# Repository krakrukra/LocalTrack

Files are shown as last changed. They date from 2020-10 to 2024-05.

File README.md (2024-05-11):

# LocalTrack  
  
#### Русская версия документации доступна [здесь](https://github.com/krakrukra/LocalTrack/blob/master/extra/wiki/rus/README.md)  
  
This device is an open source (both firmware and board level design) GPS data logger.  
You mount it with built-in magnets on some vehicle, flip the power switch and the location  
data is saved into internal flash storage. After some tracks were recorded, you can  
retrieve the device again and extract GPX track files via USB. You can then pass these  
files into mapping/analysis software of your choice, for example [viking](https://sourceforge.net/projects/viking), to get an  
easy to work with representation of recorded location data.  
  
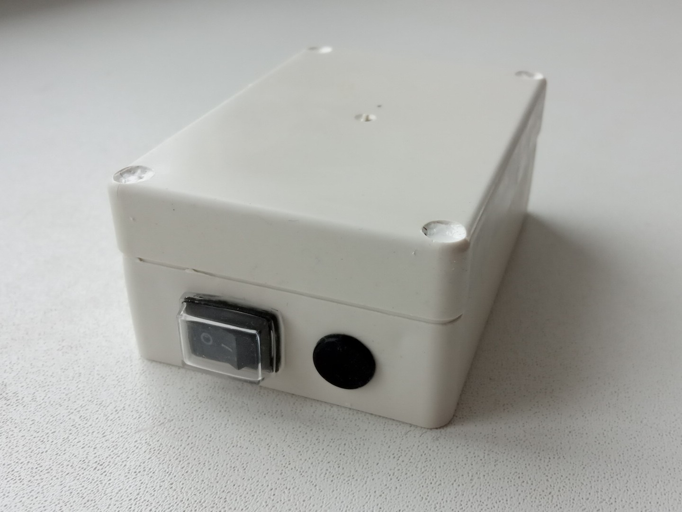
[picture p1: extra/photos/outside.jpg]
outside
  
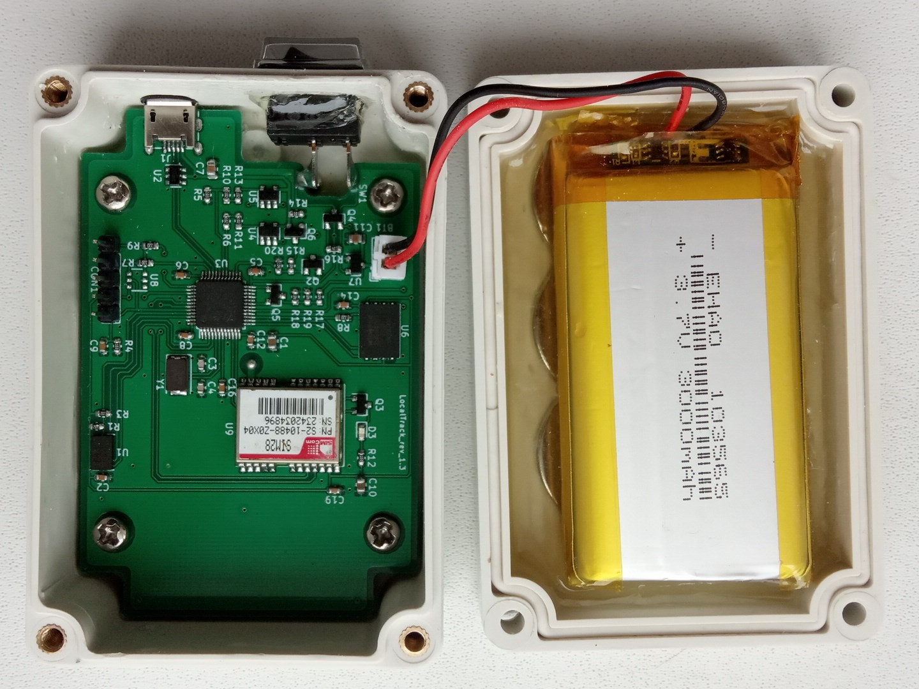
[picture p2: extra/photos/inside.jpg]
inside
  
  
This device is intended for use in applications where real-time tracking is not required,  
but other advantages of network-disconnected design are desirable, such as:  
  
1. No need to pay your cellular service provider.  
  
2. Local file storage, so you don't have to trust your data to some proprietary  
manufacturer's software or depend on a particular service being provided.  
  
3. Logger is harder to detect; if discovered, it is hard to trace where it came from,  
as it does not have information like IMEI, IMSI, payment history, etc. linked to it.  
  
4. Less power consumption and longer battery life.  
  
**CHECK THE [WIKI](https://github.com/krakrukra/LocalTrack/wiki) FOR HOW-TO-USE INFORMATION**  
  
---
  
## hardware
  
Project is designed using KiCad 6.0.11  
Check KiCad pcb file for PCB manufacturing info  
Check KiCad sch file + BOM.txt for component info  
  
Uses integrated full-speed (12Mbit/s) USB2.0 peripheral, with  
96MiB of available on-board flash memory for data storage;  
measured speeds for MSD access: read 800-850 KiB/s, write 700-750 KiB/s  
  
Fully assembled unit has dimensions of 85x55x32mm and weight of 175 grams.  
Hardware programmer device used in this project is [ST-Link V2](https://www.aliexpress.com/item/1823628996.html)  
  
SIM28 may come in several variants which have different USART speeds by default.  
Firmare here expects 9600 baudrate version. If you have different module version  
you will need to modify USART1 configuration in main.c and peripherals.c files.  
  
Device has a 3000mAh li-po battery and can function with battery voltage above 3V.  
If lower voltage is detected, device enters low battery mode and waits until  
the battery is recharged. Current consumption while tracking is around 40mA;  
while waiting in sleepmode (eg. due to lack of movement) it is less than 1mA.  
This results in about 70 hours of active tracking before battery is depleted.  
Battery can be charged via USB with up to 1A of current, so make sure to pick  
capable charging adapter and USB cable. Also, keep in mind that you will need  
a cable with extra long 8mm micro USB plug, instead of the usual 5.4mm plug.  
  
## firmware  
  
Programming language used = C  
Flashing software used = openocd 0.12.0  
IDE used = emacs text editor + Makefile  
  
The firmware was developed on debian 11.3 system, using gcc-arm-none-eabi  
toolchain (compiler, linker, binutils) and it does use gcc specific extentions.  
it was successfully compiled and tested with arm-none-eabi-gcc version 12.2.1  
  
Depends on libgcc.a, which is included in this repository. Linker script,  
startup code and openocd configuration files are included here as well.  
  
For easy in-field updates, you can use the DFU bootloader. There is a dfu  
firmware image available in **/firmware/firmware\_RRNNN.dfu** file. The name  
format is this: RR stands for board revision (13 = rev 1.3) , NNN stands  
for firmware version. For example, firmware\_13001.dfu means board  
revision 1.3, firmware version 1  

To automate firmware build process you can use make utility. If you  
open terminal in **/firmware/** directory, you could run these commands:  
  
> make  
> make upload  
> make dfu  
> make clean  
  
"make" will compile source code and create several files, among them  
is firmware.bin which contains firmware to flash. "make upload" will  
flash this file via St-Link V2 programmer. Make sure to connect the  
programmer to the board properly, before you plug it into PC and run the  
command. "make dfu" will create a DFU firmware image from firmware.bin  
which can be used later by DFU flashing software. "make clean" will  
delete all the compiled or temporary files created by previous commands.  
  
## directories info  
  
#### /firmware/ ------------- contains makefile, linker script, source files; this is a build directory  
/firmware/cmsis/ ------- header files from CMSIS compliant [STM32F0xx standard peripherals library](https://www.st.com/content/st_com/en/products/embedded-software/mcus-embedded-software/stm32-embedded-software/stm32-standard-peripheral-libraries/stsw-stm32048.html)  
/firmware/stdlib/ ---------- standard statically linked libraries (libgcc.a)  
/firmware/openocd/ ------- standard configuration files for openocd 0.12.0  
/firmware/fatfs/ ---------- [chan fatfs](http://www.elm-chan.org/fsw/ff/00index_e.html) filesystem module + W25N01GVZEIG disk driver  
/firmware/usb/ ------------ USB system and MSD class device implementation  
/firmware/main/ ------- main application files, interrupt vector table, IRQ handlers and startup code  
/firmware/dfuse-pack.py ------- python script to create .dfu firmware images  
/firmware/linkScript.ld ------- custom linker script for the GNU linker (ld)  
/firmware/Makefile ------- file used by GNU make utility for build automation  
/firmware/firmware_13NNN.dfu ------ pre-compiled firmware image in DfuSe format (STM32)  
  
#### /hardware/ ------------------- contains KiCad project, schematic, PCB files  
/hardware/LocalTrack.symbols/ ---- project specific symbol library  
/hardware/LocalTrack.pretty/ ----- project specific footprint library  
/hardware/gerbers/ ----------- gerber+excellon fabrication output files  
/hardware/BOM.txt --------- list of parts and accessories needed for DIY assembly  
  
#### /mechanical/ ------------------- contains device's mechanical information  
/mechanical/drawings/ ---- mechanical drawings for some of the parts  
/mechanical/KH-F20.FCStd --- freecad model for the plastic enclosure  
  
#### /extra/ -------------------  contains pictures, documentation, etc.  
/extra/photos/ ---------------- photos of the device  
/extra/wiki/ ------------------ github wiki pages  
  
## contact info  
  
if you have a problem / question / feature request, here are your options for contacting me:  
send me an email to krakrukra@tutanota.com  
create a new github issue (check [closed issues](https://github.com/krakrukra/LocalTrack/issues?q=is%3Aissue+is%3Aclosed) first)  
also, you can check out my [youtube channel](https://www.youtube.com/channel/UC8HZCV1vNmZvp7ci1vNmj7g)  
  
For extra security, you could use my PGP public key saved in [/extra/pubkey.asc](https://github.com/krakrukra/LocalTrack/blob/master/extra/pubkey.asc).

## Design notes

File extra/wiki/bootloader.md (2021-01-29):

LocalTrack provides end user an ablity to update firmware  
over USB using DFU bootloader. To do so, you will need to  
install some dedicated software on your PC and connect the  
LocalTrack to this same PC, while your device is in DFU mode.  
Then, you feed a particular firmware image in DfuSe format  
to this dedicated software and wait for it to finish the update.  
The latest firmware image is available in the repository, in  
**/firmware/firmware_13nnn.dfu** file, where nnn is a number  
which stands for firmware version (eg. firmware_13000.dfu);  
  
There are 2 ways to enter DFU mode. If your device is already  
functional, you can get into DFU mode by adding "ENTER_DFU_MODE"  
configuration command to config.txt file. Once you disconnect  
LocalTrack from PC and then connect it again, device will delete  
config.txt and enter DFU mode instead of usual disk mode. To  
exit DFU mode you need to disconnect device from the host PC  
and power the device off using the switch.  
  
If the previous firmware on the device is corrupted/nonexistent,  
you will have to power the device off with the switch and then  
short out boot0 pin to 3.3V line. This will require you to take  
the lid off. Be careful, as there are wires connecting the board  
with battery mounted on the lid. You will then see a 5 pin header  
where you should connect 2 pins (using a jumper or some other  
means) which are the farthest away from a nearby screw. Only  
then connect the device and it will enter DFU mode right away;  
  
---
  
#### linux (debian) DFU update procedure  
  
1. install dfu-util (sudo apt-get install dfu-util)  
2. download this repository (.zip) to your PC and unpack it  
3. connect the device to PC with a USB cable  
4. add "ENTER_DFU_MODE" command to config.txt  
5. eject the drive and disconnect device from PC  
6. wait for 1-2 seconds and connect it back again  
7. open terminal window in /firmware/ directory  
8. run command: dfu-util -a 0 -D firmware_13nnn.dfu  
9. wait for update process to finish  
10. toggle the power switch off and diconnect  
  
#### windows DFU update procedure  
  
1. download and install [DfuSe demo](https://www.st.com/en/development-tools/stsw-stm32080.html) software  
2. download this repository (.zip) to your PC and unpack it  
3. connect the device to PC with a USB cable  
4. add "ENTER_DFU_MODE" command to config.txt  
5. eject the drive and disconnect device from PC  
6. wait for 1-2 seconds and connect it back again  
7. start DfuSe demo, click on "Choose" button (bottom right)  
8. select the /firmware/firmware_13nnn.dfu file  
9. select "Internal Flash" as target region (Target ID = 00)  
10. click on "Upgrade" button (bottom right)  
11. confirm by clicking "yes", wait for update process  
12. toggle the power switch off and disconnect

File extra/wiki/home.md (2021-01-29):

LocalTrack GPS logger uses internal 96MiB flash memory to store  
location data. It requires FAT16 or FAT32 filesystem on the first  
partition (MBR partition table), and will place all the track  
files there. Track files are saved in GPX format, which is widely  
used and should be easily accepted by many different mapping  
softwares. If necessary, you can use a program for file format  
conversion, for example [gpsbabel](https://www.gpsbabel.org).  
  
Once you power the device ON with the switch, it will try to receive  
signal from available GPS sattelites. If a valid position fix is acquired,  
a new trackpoint will be added to current GPX track. Each GPX track  
has a name in this format: **HH:MM:SS**, where HH is hour in 24-hour  
format, MM is minute, SS is second of when the GPX track was started.  
Tracks are grouped into files, with file names like this: **YY-MM-DD.GPX**,  
where YY is year (since 2000), MM is a month number (from 1 to 12),  
DD is day of month (1 to 31) of when the file was created. So, a file  
called 21-10-05.GPX will contain tracks which started on Oct. 5, 2021.  
  
To increase battery life, device enters sleep mode when it sees no  
movement for 120 seconds. When this happends, current track will be  
completed. After some movement activity is detected again, device  
wakes up and all the new incoming data is put into a new track.  
After enough data was saved, you retrieve the device and connect it  
to your PC via USB interface. It will show up as a mass storage  
device (USB flash drive) and you will be able to take all the GPX  
files from there and feed them to some mapping software, eg. [viking](https://sourceforge.net/projects/viking).  
  
Optionally, you can have a **config.txt** file in the root directory.  
This is the file where configuration commands can be placed.  
These commands alter the behaviour of LocalTrack, such as  
setting different fix interval, adding extra information to each  
trackpoint, performing mass erase operations on flash memory, etc.  
You can find more info about that in dedicated wiki pages.  
  
#### Read other wiki pages:  
* [configuration](https://github.com/krakrukra/LocalTrack/wiki/configuration)  
* [DFU bootloader](https://github.com/krakrukra/LocalTrack/wiki/bootloader)  
  
#### Some tutorial videos are available on my [youtube channel](https://www.youtube.com/channel/UC8HZCV1vNmZvp7ci1vNmj7g)

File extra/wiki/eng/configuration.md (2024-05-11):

LocalTrack provides several configuration options with which you can  
further specify how exactly the device should behave once powered on.  
Such behaviour changes are done through the use of configuration  
commands. These commands are placed inside of a text file named  
**config.txt** in the root directory of LocalTrack's USB storage.  
  
Here is a quick summary of the rules:  
  
1. Text encoding must be ASCII. Quotation marks used here are not parts  
of commands and are just used to indicate start and end of a command.  
  
2. All configuration commands must be placed at the start of  
the line and terminated with a newline character.  
  
3. Some commands take decimal number as argument, which follows the  
command keyword. These commands have **n** character shown here, which  
should be replaced with an actual number in config.txt; The command  
and it's argument must be separated by exactly one space character.  
  
4. If some command is not present in config.txt default value for  
the corresponding configuration setting is used.  
  
### Below is a complete list of all configuration commands:  
  
* "FIX_INTERVAL **n**"   --- sets fix interval in milliseconds  
* "UTC_OFFSET +**n**"   --- sets positive offset of local time relative to UTC time  
* "UTC_OFFSET -**n**"   --- sets negative offset of local time relative to UTC time  
* "ALLOW_SHORT_TRACKS"   --- save all tracks, even if shorter than 3 minutes  
* "DISABLE_1PPS_LED"   --- prevents blue status LED from blinking every second 
* "ENTER_DFU_MODE"   --- enter USB DFU mode next time device is plugged in  
* "REPORT_SPEED"   --- add speed info (in meters/sec) to each trackpoint  
* "REPORT_COURSE"   --- add course info (in degrees) to each trackpoint  
* "REPORT_NUMSAT"   --- add number of sattelites used to each trackpoint  
* "REPORT_FIXTYPE"   --- add fix type info (none, 2d or 3d) to each trackpoint  
* "MASS_ERASE"   --- unrecoverably erase all flash memory blocks  
  
---
  
1. "FIX_INTERVAL **n**" command allows user to change default fix interval of 1000ms.  
Accepted values are integers in the range of 200 to 10000. Lower values will  
give you more detailed tracks (more trackpoints) but also take more disk space.  
For example, "FIX_INTERVAL 200" will result in making 5 trackpoints per second.  
  
2. "UTC_OFFSET +**n**" and "UTC_OFFSET -**n**" commands set positive/negative offset  
in minutes of local time relative to UTC time. Accepted values are integers  
from 0 to 1440, default value is 0. Local time is used in track and file names.  
For example, "UTC_OFFSET +180" command will set local timezone to UTC+3.  
  
3. "ALLOW_SHORT_TRACKS" command makes the device save all valid tracks, while by  
default only tracks of 3 minutes or more are kept to prevent spam. This command  
is intended for debugging / testing and it is not recommended in normal use.  
  
4. "DISABLE_1PPS_LED" command disables blue status LED, which normally blinks  
once per second while receiver gets valid position fixes. The main purpose  
of this command is to make device a bit more covert in complete darkness.  
  
5. "ENTER_DFU_MODE" command will make the device enter DFU mode next  
time it is connected to host PC via USB, while normally it would act as USB  
disk. To prevent repeated DFU entry config.txt file will be deleted. In order  
to exit DFU mode you will have to put the power switch in OFF position and  
disconnect the USB cable.  
  
6. "REPORT_SPEED", "REPORT_COURSE", "REPORT_NUMSAT", "REPORT_FIXTYPE"  
commands add additional information to each GPX trackpoint. By default, all of  
this information is omitted. If enabled, speed is reported in meters per second,  
course is reported in degrees relative to true north in WGS84 datum,  
number of sattelites will show you a number (0 to 12) of sattelites used  
to make position fix, fix type will give you a status string (2d or 3d).  
  
7. "MASS_ERASE" command will erase all the data blocks on the device which contain,  
or have previously contained any data next time USB cable is connected to a PC. The  
process takes just a few seconds. Keep in mind, that any stored files and partition  
table will be lost. This command is mainly intended to be a quick way to unrecoverably  
erase all the data on the device, without having to manually overwrite all logical  
blocks for a couple of times.

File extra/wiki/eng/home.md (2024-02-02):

#### Русская версия документации доступна [здесь](https://github.com/krakrukra/LocalTrack/blob/master/extra/wiki/rus/home.md)  
  
LocalTrack GPS logger uses internal 96MiB flash memory to store  
location data. It requires FAT16 or FAT32 filesystem on the first  
partition (MBR partition table), and will place all the track  
files there. Track files are saved in GPX format, which is widely  
used and should be easily accepted by many different mapping  
softwares. If necessary, you can use a program for file format  
conversion, for example [gpsbabel](https://www.gpsbabel.org).  
  
Once you power the device ON with the switch, it will try to receive  
signal from available GPS sattelites. If a valid position fix is acquired,  
a new trackpoint will be added to current GPX track. After a set period  
of time elapses (1s by default) the next point will be added. Each GPX track  
has a name in this format: **HH:MM:SS**, where HH is hour in 24-hour  
format, MM is minute, SS is second of when the GPX track was started.  
Tracks are grouped into files, with file names like this: **YY-MM-DD.GPX**,  
where YY is year (since 2000), MM is a month number (from 1 to 12),  
DD is day of month (1 to 31) of when the file was created. So, a file  
called 21-10-05.GPX will contain tracks which started on Oct. 5, 2021.  
  
To increase battery life, device enters sleep mode when it sees no  
movement for 120 seconds. When this happends, current track will be  
completed. After some movement activity is detected again, device  
wakes up and all the new incoming data is put into a new track.  
After enough data was saved, you retrieve the device and connect it  
to your PC via USB interface. It will show up as a mass storage  
device (USB flash drive) and you will be able to take all the GPX  
files from there and feed them to some mapping software, eg. [viking](https://sourceforge.net/projects/viking).  
  
Optionally, you can have a **config.txt** file in the root directory.  
This is the file where configuration commands can be placed.  
These commands alter the behaviour of LocalTrack, such as  
setting different fix interval, adding extra information to each  
trackpoint, performing mass erase operations on flash memory, etc.  
You can find more info about that in dedicated wiki pages.  
  
#### Read other wiki pages:  
* [configuration](https://github.com/krakrukra/LocalTrack/wiki/configuration)  
* [status file](https://github.com/krakrukra/LocalTrack/wiki/status)  
* [DFU bootloader](https://github.com/krakrukra/LocalTrack/wiki/bootloader)  
  
#### Some tutorial videos are available on my [youtube channel](https://www.youtube.com/channel/UC8HZCV1vNmZvp7ci1vNmj7g)

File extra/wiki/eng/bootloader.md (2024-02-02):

LocalTrack provides end user an ablity to update firmware  
over USB using DFU bootloader. To do so, you will need to  
install some dedicated software on your PC and connect the  
LocalTrack to this same PC, while your device is in DFU mode.  
Then, you feed a particular firmware image in DfuSe format  
to this dedicated software and wait for it to finish the update.  
The latest firmware image is available in the repository, in  
**/firmware/firmware_13nnn.dfu** file, where nnn is a number  
which stands for firmware version (eg. firmware_13001.dfu);  
  
There are 2 ways to enter DFU mode. If your device is already  
functional, you can get into DFU mode by adding "ENTER_DFU_MODE"  
configuration command to config.txt file. Once you disconnect  
LocalTrack from PC and then connect it again, device will delete  
config.txt and enter DFU mode instead of usual disk mode. To  
exit DFU mode you need to disconnect device from the host PC  
and power the device off using the switch.  
  
If the previous firmware on the device is corrupted/nonexistent,  
you will have to power the device off with the switch and then  
short out boot0 pin to 3.3V line. This will require you to take  
the lid off. Be careful, as there are wires connecting the board  
with battery mounted on the lid. You will then see a 5 pin header  
where you should connect 2 pins (using a jumper or some other  
means) which are the farthest away from a nearby screw. Only then  
connect the device via USB and it will enter DFU mode right away;  
  
---
  
#### linux (debian) DFU update procedure  
  
1. install dfu-util (sudo apt-get install dfu-util)  
2. download this repository (.zip) to your PC and unpack it  
3. make sure device power switch is turned OFF  
4. connect the device to PC with a USB cable  
5. add "ENTER_DFU_MODE" command to config.txt  
6. eject the drive and disconnect device from PC  
7. wait for 1-2 seconds and connect it back again  
8. open terminal window in /firmware/ directory  
9. run command: dfu-util -a 0 -D firmware_13nnn.dfu  
10. wait for update process to finish  
11. disconnect your device from PC  
  
#### windows DFU update procedure  
  
1. download and install [DfuSe demo](https://www.st.com/en/development-tools/stsw-stm32080.html) software  
2. download this repository (.zip) to your PC and unpack it  
3. make sure device power switch is turned OFF  
4. connect the device to PC with a USB cable  
5. add "ENTER_DFU_MODE" command to config.txt  
6. eject the drive and disconnect device from PC  
7. wait for 1-2 seconds and connect it back again  
8. start DfuSe demo, click on "Choose" button (bottom right)  
9. select the /firmware/firmware_13nnn.dfu file  
10. select "Internal Flash" as target region (Target ID = 00)  
11. click on "Upgrade" button (bottom right)  
12. confirm by clicking "yes", wait for update process  
13. disconnect your device from PC

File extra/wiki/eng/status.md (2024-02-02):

Every time device is plugged into a host PC it saves latest  
status data into a file inside of it's own root directory.  
Name of the file is **STATUS.TXT**. This status data includes  
battery charge (in volts and % of full charge), operation  
mode (Autonomous / DGPS / Fix not available), number of  
visible sattelites (0 to 12); PDOP, HDOP, VDOP values (0 to 50)  
These values are sampled at the moment when USB connection  
is established, and will only be updated again if device is  
disconnected and connected back to PC. Status data also  
includes the maximum number of GPS sattelites in sight since  
device was powered on or since last status file was created.  
Status data can look something like this:  
  
Battery status: 4.12V 91%  
Operation mode: Autonomous  
Satellites used now: 6  
Max number of satellites: 9  
PDOP: 1.74  
HDOP: 1.45  
VDOP: 0.96  
  
Battery status is also saved every time a new GPX track  
has started, and placed into track's comment string, so  
you can monitor historical data this way.  
Max number of sattelites value is useful in cases when  
GPS signal is weak or jammed so you will know why you  
are not getting any data recorded in such cases.  
PDOP means Position Dilution of Precision, HDOP -  
Horizontal Dilution of Precision, VDOP - Vertical  
Dilution of Precision. These values characterise how  
precise your current GPS fix is, the colser this value  
is to 0 the better. Maximum reported value is 50, so  
when value 50 is reported, the actual DOP may be much  
larger.

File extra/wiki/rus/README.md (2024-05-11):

# LocalTrack  
  
Это устройство является GPS логгером (регистратором) с открытыми исходными файлами (прошивка и плата).  
Вы устанавливаете его с помощью встроенных магнитов на какой-либо автомобиль, включаете и данные  
сохраняются во внутреннюю флэш-память. После того, как некоторые маршруты были записаны, вы можете  
снова забрать устройство и извлечь GPX файлы маршрутов через USB. Затем вы можете загрузить эти  
файлы в программу для картографирования/анализа данных по вашему выбору, например [viking](https://sourceforge.net/projects/viking), чтобы  
получить информацию о маршрутах в максимально удобном виде.  
  
outside  
inside  
  
Это устройство предназначено для использования в ситуациях, где не требуется отслеживание в реальном  
времени, но желательны другие преимущества устройства без подключения к сети, такие как:  
  
1. Не нужно платить своему оператору сотовой связи.  
  
2. Файлы хранятся в устройстве, поэтому вам не придется доверять свои данные каким-то проприетарным  
программам производителя и не придётся зависеть от предоставляемых им услуг.  
  
3. Регистратор труднее обнаружить; если его обнаружат, трудно отследить, откуда он взялся,  
поскольку с ним не связана такая информация, как IMEI, IMSI, история платежей, итд.  
  
4. Меньшее энергопотребление и более длительный срок службы батареи.  
  
**ИНСТРУКЦИЯ ПО ПРИМЕНЕНИЮ ЕСТЬ НА [ВИКИ](https://github.com/krakrukra/LocalTrack/blob/master/extra/wiki/rus/home.md)**  
  
---
  
## аппаратная часть  
  
Проект разработан с использованием KiCad 6.0.11.  
Изучите pcb файл KiCad для информации по печатной плате  
Изучите BOM.txt и sch файл KiCad для информации по деталям  
  
Используется встроенное переферийное устройство USB2.0 full-speed (12Мбит/с),  
а также чип памяти дающий ёмкость в 96МиБ для хранения файлов.  
Измеренная скорость доступа к диску: чтение 800-850КиБ/c, запись 700-750 КиБ/с  
  
В собранном виде устройство имеет размеры 85х55х32мм и вес 175 грамм.  
Программатор используемый для прошивки устройства - [ST-Link V2](https://www.aliexpress.ru/item/1823628996.html)  
  
SIM28 выпускается в нескольких вариантах, которые по умолчанию имеют разные скорости USART.  
Прошивка устройства ожидает версию со скоростью 9600 бит/c. Если у вас другая версия модуля  
вам нужно будет изменить конфигурацию USART1 в файлах main.c и peripherals.c  
  
Устройство оснащено литий-ионным аккумулятором ёмкостью 3000 мАч и работает при напряжении выше 3 В.  
Если обнаружено более низкое напряжение, устройство переходит в режим разряженной батареи и ждёт,  
пока аккумулятор будет заряжен. Потребление тока в рабочем режиме составляет около 40 мА;  
во время ожидания в спящем режиме (например, из-за отсутствия движения) оно составляет менее 1 мА.  
Это обеспечивает около 70 часов активного отслеживания, прежде чем батарея разрядится.  
Аккумулятор можно заряжать через USB током до 1 А, поэтому обязательно выбирайте  
подходящий адаптер и USB-кабель для зарядки. Также имейте в виду, что вам понадобится  
кабель с удлинённым разъёмом micro-USB длиной 8 мм вместо обычного разъёма длиной 5,4 мм.  
  
## прошивка  
  
язык программирования = C  
ПО для прошивки = openocd 0.12.0  
среда разработки = emacs + Makefile  
  
Прошивка разработана на системе debian 11.3 с использованием пакета gcc-arm-none-eabi  
(компилятор, компоновщик, бинарные утилиты) и использует расширения компилятора gcc.  
Она была успешно скомпилирована и протестирована с arm-none-eabi-gcc версии 12.2.1  
  
Имеет зависимость от библиотеки libgcc.a, она содержится в репозитории. Скрипт  
компоновщика, стартовый код, и файлы конфигурации openocd также содержатся в нём.  
  
Для записи прошивки можно использовать DFU загрузчик. В репозитории есть DFU  
образ прошивки в файле **/firmware/firmware\_RRNNN.dfu**; название записано в  
таком формате: RR - это версия платы (13 = плата 1.3) , NNN - это версия прошивки.  
Например, firmware\_13002.dfu это файл для платы версии 1.3 с прошивкой версии 2.  

Для автоматизации процесса компиляции применяется утилита make. Если вы откроете  
командную строку в каталоге **/firmware/** вы сможете запустить эти команды:  
  
> make  
> make upload  
> make dfu  
> make clean  
  
"make" компилирует исходный код и создает несколько файлов, среди которых  
есть firmware.bin который и нужно записать в память устройства. "make upload"  
через программатор ST-Link V2 запишет этот файл. Для этого нужно заранее  
правильно подключить плату к программатору, а затем и сам программатор к ПК.  
"make dfu" создаёт из firmware.bin образ dfu для загрузчика, который потом  
можно будет использовать для прошивки без программатора. "make clean"  
удалит все временные и промежуточные файлы созданные предыдущими командами.  
  
## содержание каталогов  
  
#### /firmware/ ------------- содержит makefile, скрипт компоновщика, исходный код, промежуточные файлы  
/firmware/cmsis/ ------- заголовочные файлы из CMSIS библиотеки [STM32F0xx standard peripherals](https://www.st.com/content/st_com/en/products/embedded-software/mcus-embedded-software/stm32-embedded-software/stm32-standard-peripheral-libraries/stsw-stm32048.html)  
/firmware/stdlib/ ---------- стандартные статические библиотеки (libgcc.a)  
/firmware/openocd/ ------- стандартные файлы конфигурации для openocd 0.12.0  
/firmware/fatfs/ ---------- библиотека файловой системы [chan fatfs](http://www.elm-chan.org/fsw/ff/00index_e.html) + собственный драйвер W25N01GVZEIG  
/firmware/usb/ ------------ собственный USB стек, реализация устройства MSD класса  
/firmware/main/ ------- основаная программа, таблица адресов прерываний, стартовый код, функции прерываний  
/firmware/dfuse-pack.py ------- скрипт в python для создания .dfu образов прошивки  
/firmware/linkScript.ld ------- специальный скрипт для GNU компоновщика (ld)  
/firmware/Makefile ------- файл используемый утилитой автоматизации GNU make  
/firmware/firmware_13NNN.dfu ------ заранее скомпилированный образ прошивки в формате DfuSe (STM32)  
  
#### /hardware/ -------------------содержит KiCad проект, файлы схемы и печатной платы  
/hardware/LocalTrack.symbols/ ---- библиотека символов для схемы проекта  
/hardware/LocalTrack.pretty/ ----- библиотека деталей для платы проекта  
/hardware/gerbers/ ----------- gerber+excellon файлы для производства  
/hardware/BOM.txt --------- список деталей для самостоятельной закупки и сборки  
  
#### /mechanical/ ------------------- содержит механическую информацию по устройству  
/mechanical/drawings/ ---- чертежи используемых деталей  
/mechanical/KH-F20.FCStd --- freecad модель пластикового корпуса  
  
#### /extra/ -------------------  содержит картинки, документы, итд.  
/extra/photos/ ---------------- фото устройства  
/extra/wiki/ ------------------ страницы вики для github  
  
## контактная информация  
  
Если у вас есть проблема / вопрос / предложение, то вот несколько способов связаться со мной:  
отправьте email на krakrukra@tutanota.com  
создайте новый вопрос на github (сначала проверьте [уже закрытые](https://github.com/krakrukra/LocalTrack/issues?q=is%3Aissue+is%3Aclosed))  
также можно использовать соцсети, например мой [канал на youtube](https://www.youtube.com/channel/UC8HZCV1vNmZvp7ci1vNmj7g),  
[группу ВК](https://vk.com/krakrukra) или мой [телеграм канал](https://t.me/krakrukra)  
  
#### где купить:  
  
Купить можно напрямую связавшись со мной (например через email) или через авито:  
https://www.avito.ru/voronezh/zapchasti_i_aksessuary/gps_logger_localtrack_3932453518

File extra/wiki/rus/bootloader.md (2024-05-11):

LocalTrack предоставляет конечному пользователю возможность обновлять  
прошивку через USB с использованием DFU загрузчика. Для этого вам  
нужно будет установить специальное программное обеспечение на вашем ПК  
и подключить LocalTrack в этот же компьютер, перевести ваше устройство  
в режим DFU. Затем вы используете образ прошивки в формате DfuSe и с  
помощью этой специальной программы записать прошивку в память устройства.  
Последняя версия прошивки в DfuSe формате доступна в репозитории, в  
файле **/firmware/firmware_13nnn.dfu**, где nnn - число обозначающее  
версию прошивки (например, firmware_13001.dfu);  
  
Есть 2 способа перевести устройство в режим DFU. Если ваше устройство  
уже работает, вы можете попасть в режим DFU, добавив команду конфигурации  
"ENTER_DFU_MODE" в файл config.txt. Как только вы отключите LocalTrack  
от компьютера, а затем подключите его снова, устройство удалит config.txt  
и войдёт в режим DFU вместо обычного дискового режима. Чтобы выйти из  
из режима DFU, вам нужно отключить устройство от компьютера и отключить  
питание устройства используя переключатель.  
  
Если предыдущая прошивка на устройстве повреждена/не существует,  
вам придется выключить устройство с помощью переключателя, а затем  
cоединить вывод BOOT0 и линию 3,3 В. Для этого нужно будет снять  
крышку с устройства. Будьте осторожны, чтобы не повредить провода  
соединяющие плату с аккумулятором, установленным на крышке. На плате  
вы увидите 5-контактный разъём, где нужно будет соединить 2 контакта  
(с помощью перемычки или каких-либо других средств), которые являются  
самыми дальними от близлежащего винта. Затем подключите устройство  
через USB и оно сразу же войдет в режим DFU;  
  
---  
  
#### Процедура обновления через DFU на Linux (Debian)  
  
1. Установите утилиту dfu-util (sudo apt-get install dfu-util)  
2. Загрузите этот репозиторий (.zip) на свой компьютер и разархивируйте его  
3. Отключите питание устройства с помощью переключателя  
4. Подключите устройство к ПК через USB кабель  
5. Добавьте команду "ENTER_DFU_MODE" в файл config.txt  
6. Отключите устройство от компьютера  
7. Подождите 1-2 секунды и подключите снова  
8. Откройте окно терминала в папке /firmware/  
9. Запустите команду: dfu-util -a 0 -D firmware_13nnn.dfu  
10. Дождитесь завершения процесса обновления  
11. Отключите устройство от компьютера  
  
#### Процедура обновления через DFU на Windows  
  
1. Загрузите утилиту dfu-util c [официального сайта](https://sourceforge.net/projects/dfu-util/files/)  
2. Загрузите установщик USB драйверов [Zadig](https://zadig.akeo.ie/)  
3. Отключите питание устройства с помощью переключателя  
4. Подключите устройство к ПК через USB кабель  
5. Добавьте команду "ENTER_DFU_MODE" в файл config.txt  
6. Отключите устройство от компьютера  
7. Подождите 1-2 секунды и подключите снова  
8. Запустите Zadig, выберите устройство STM32 BOOTLOADER  
9. Используя Zadig, установите драйвер WinUSB для загрузчика  
10. Загрузите этот репозиторий (.zip) на свой компьютер и разархивируйте его  
11. Откройте окно терминала в папке /firmware/  
12. Запустите команду: DFUPATH\dfu-util.exe -a 0 -D .\firmware_13nnn.dfu  
13. Дождитесь завершения процесса обновления  
14. Отключите устройство от компьютера  
  
DFUPATH - это абсолютный адрес каталога в котором находится dfu-util.exe

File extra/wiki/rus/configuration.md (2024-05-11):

LocalTrack предоставляет несколько вариантов конфигурации, с помощью  
которых вы можете настроить, как именно устройство должно вести себя  
после включения. Такие изменения поведения выполняются с помощью команд  
конфигурации. Эти команды помещаются внутри текстового файла с именем  
**config.txt** в корневом каталоге USB-диска встроенного в устройство.  
  
Вот краткое изложение правил:  
  
1. Кодировка текста должна быть ASCII. Используемые здесь кавычки не являются  
частями команд и используются только для обозначения начала и конца команды.  
  
2. Все команды конфигурации должны располагаться в начале  
строки и завершаться символом новой строки.  
  
3. Некоторые команды принимают в качестве аргумента десятичное число, которое следует за  
ключевым словом команды. Для этих команд здесь используется символ **n**, который  
нужно будет заменить соответствующим числом в config.txt; Команда и её аргумент  
должны быть разделены ровно одним символом пробела.  
  
4. Если какая-либо команда отсутствует в config.txt либо отсутствует сам файл, для  
параметра конфигурации будет использовано значение по умолчанию.  
  
### Ниже приведен полный список всех команд конфигурации:  
  
* "FIX_INTERVAL **n**" --- устанавливает интервал между точками маршрута в миллисекундах  
* "UTC_OFFSET +**n**" --- устанавливает положительное смещение местного времени относительно UTC  
* "UTC_OFFSET -**n**" --- устанавливает отрицательное смещение местного времени относительно UTC  
* "ALLOW_SHORT_TRACKS" --- сохранять все маршруты, даже если их продолжительность меньше 3 минут  
* "DISABLE_1PPS_LED" --- предотвращает мигание синего светодиода каждую секунду  
* "ENTER_DFU_MODE" --- войти в режим DFU загрузчика при следующем подключении устройства по USB  
* "REPORT_SPEED" --- добавить информацию о скорости (в метрах/сек) в каждой точке маршрута  
* "REPORT_COURSE" --- добавить информацию о курсе (в градусах) в каждой точке маршрута  
* "REPORT_NUMSAT" --- добавить количество спутников, используемых для каждой точки маршрута  
* "REPORT_FIXTYPE" --- добавить информацию о координатах (нет, 2d или 3d) для каждой точки маршрута  
* "MASS_ERASE" --- безвозвратно стереть все блоки флэш-памяти  
  
---
  
1. Команда "FIX_INTERVAL **n**" позволяет пользователю изменить время между точками,  
по умолчанию равное 1000 мс. Допустимые значения — целые числа в диапазоне от 200  
до 10000. Меньшие значения дадут вам более подробные маршруты (больше точек), но они  
также занимают больше места на диске. Например, "FIX_INTERVAL 200" приведет к записи  
5 точек маршрута в секунду.  
  
2. Команды "UTC_OFFSET +**n**" и "UTC_OFFSET -**n**" устанавливают положительное/отрицательное  
смещение в минутах местного времени относительно UTC. Допустимые значения являются целыми числами  
от 0 до 1440, значение по умолчанию = 0. Местное время используется в именах маршрутов и файлов.  
Например, команда "UTC_OFFSET +180" установит местный часовой пояс как UTC+3.  
  
3. Команда "ALLOW_SHORT_TRACKS" заставляет устройство сохранять все записанные маршруты,  
при том, что по умолчанию сохраняются только треки продолжительностью 3 минуты и более,  
чтобы предотвратить спам. Эта команда предназначена для отладки/тестирования и  
не рекомендуется при обычном использовании.  
  
4. Команда "DISABLE_1PPS_LED" отключает синий светодиод состояния, который обычно мигает  
один раз в секунду, пока приемник получает сигнал с GPS спутников. Главная цель этой  
команды это сделать устройство более скрытным в полной темноте.  
  
5. Команда "ENTER_DFU_MODE" переведет устройство в режим DFU загрузчика при следующем  
подключеннии к компьютеру через USB, хотя обычно устройство работает как USB диск.  
Чтобы предотвратить повторное включение DFU режима, файл config.txt будет удалён.  
Чтобы выйти из режима DFU вам нужно будет отсоединить USB-кабель и перевести выключатель  
питания в положение ВЫКЛ.  
  
6. Команды "REPORT_SPEED", "REPORT_COURSE", "REPORT_NUMSAT", "REPORT_FIXTYPE" добавляют  
дополнительную информацию к каждой точке GPX маршрута. По умолчанию вся эта информация  
не записывается. Если эти параметры включены, скорость отображается в метрах в секунду,  
курс указывается в градусах относительно истинного севера в системе координат WGS84,  
количество спутников покажет вам количество (от 0 до 12) используемых GPS спутников.  
Тип точки предоставит вам строку состояния (имеет точка 2d или 3d координаты).  
  
7. Команда "MASS_ERASE" при следующем подключении по USB стирает все блоки памяти на  
устройстве, которые содержат или ранее содержали какие-либо данные. Процесс занимает  
всего несколько секунд. Имейте в виду, что все сохраненные файлы и таблица разделов  
будут потеряны. Эта команда в основном предназначена для быстрого безвозвратного  
стирания всех данных на устройстве, без необходимости несколько раз вручную  
перезаписывать все блоки памяти.

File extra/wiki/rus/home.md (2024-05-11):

GPS-регистратор LocalTrack использует внутреннюю флэш-память объёмом 96 МиБ для  
хранения файлов маршрутов. Для работы требуется файловая система FAT16 или FAT32  
в первом разделе (таблица разделов MBR) и именно туда будут сохраняться данные.  
Файлы маршрутов сохраняются в формате GPX, который широко распространён, и должны  
быть легко прочитаны многими различными картографическими программами. В случае  
необходимости можно воспользоваться программой для изменения формата файлов,  
например [gpsbabel](https://www.gpsbabel.org).  
  
Как только вы включите устройство с помощью переключателя, оно попытается получить  
сигнал от доступных спутников GPS. Если местоположение устройства успешно получено,  
к текущему GPX маршруту будет добавлена новая точка, а по прошествию заданного  
времени (по умолчанию 1 с) будет добавлена следующая. Каждый такой маршрут имеет имя  
в следующем формате: **ЧЧ:ММ:СС**, где ЧЧ - это час, MM - минута, СС - секунда когда  
началась запись GPX маршрута. Сами маршруты сохраняются вместе в соответствующие файлы  
со следующими именами: **ГГ-ММ-ДД.GPX**, где ГГ - год (с 2000 г.), ММ - номер месяца  
(от 1 до 12), ДД - день месяца (от 1 до 31), когда маршрут был создан. То есть, файл  
под названием 21-10-05.GPX будет содержать все маршруты, начавшиеся 5 октября 2021 года.  
  
Чтобы увеличить срок службы батареи, устройство переходит в спящий режим когда не  
видит движения в течение 120 секунд. В этом случае текущий маршрут будет завершён.  
После того как устройство снова обнаружит движение, оно выйдет из спящего режима  
и все новые входящие данные будут сохранены в новый маршрут. После того, как будет  
сохранено достаточно данных, вы забираете устройство и подключаете его к вашему  
ПК через интерфейс USB. Устройство будет отображаться как USB диск и вы сможете  
достать все GPX файлы оттуда и прочитать их в подходящей программе, например [viking](https://sourceforge.net/projects/viking).  
  
При желании вы можете иметь файл **config.txt** в корневом каталоге. Это файл,  
в который можно поместить команды конфигурации. Эти команды изменяют поведение  
устройства, например: установка временных интервалов между точками, добавление  
дополнительной информации к каждой точке маршрута, запуск массового стирания  
флэш-памяти, итд. Дополнительную информацию об этом можно найти на страницах вики.  
  
#### Другие страницы документации:  
* [конфигурация](https://github.com/krakrukra/LocalTrack/blob/master/extra/wiki/rus/configuration.md)  
* [файл состояния](https://github.com/krakrukra/LocalTrack/blob/master/extra/wiki/rus/status.md)  
* [DFU загрузчик](https://github.com/krakrukra/LocalTrack/blob/master/extra/wiki/rus/bootloader.md)  
  
#### На моём [youtube канале](https://www.youtube.com/channel/UC8HZCV1vNmZvp7ci1vNmj7g) есть видео по применению устройства

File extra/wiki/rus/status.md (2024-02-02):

Каждый раз, когда устройство подключается к компьютеру информация  
о статусе устройства сохраняется в файл внутри корневого каталога.  
Имя файла - **STATUS.TXT**. Эти данные о состоянии включают в себя  
заряд батареи (в вольтах и % от полной зарядки), режим работы  
(автономный / DGPS / нет спутников), количество видимых спутников  
GPS (от 0 до 12); значения PDOP, HDOP, VDOP (от 0 до 50);  
Эти значения сохраняются в тот момент, когда появляется USB  
соединение и будут снова обновлены только в том случае, если  
устройство будет отключено и подключено к компьютеру снова.  
Данные о статусе также включают в себя максимальное количество  
GPS спутников в поле зрения устройства с момента его включения  
или создания предыдущего статусного файла. Эти данные могут  
выглядеть так:  
  
Battery status: 4.12V 91%  
Operation mode: Autonomous  
Satellites used now: 6  
Max number of satellites: 9  
PDOP: 1.74  
HDOP: 1.45  
VDOP: 0.96  
  
Состояние батареи также сохраняется каждый раз при создании нового  
GPX маршрута и помещается в строку комментария. Таким образом  
вы можете отслеживать историю разряда батареи.  
Максимальное количество GPS спутников полезно в тех случаях, когда  
сигнал GPS слаб или заглушён. Так вы сможете узнать, почему в  
некоторых случаях устройство не смогло записать маршрут.  
PDOP означает Position Dilution of Precision, HDOP - Horizontal  
Dilution of Precision, VDOP - Vertical Dilution of Precision.  
Эти значения характеризуют, насколько точно были определены  
текущие координаты устройства. Чем ближе это значение к 0,  
тем лучше. Максимальное значение которое показывает устройство  
это 50, поэтому когда показания DOP = 50, фактически они могут  
быть ещё больше.

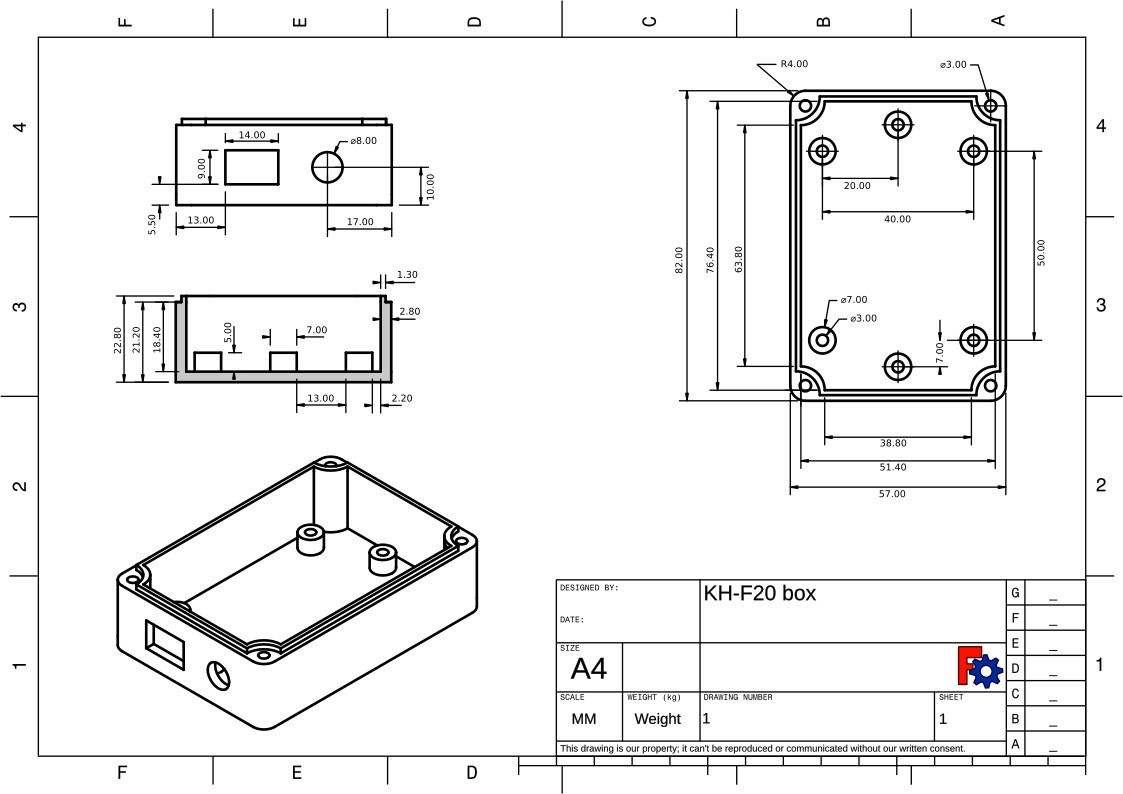
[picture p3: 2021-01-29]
mechanical/drawings/KH-F20_box.jpg

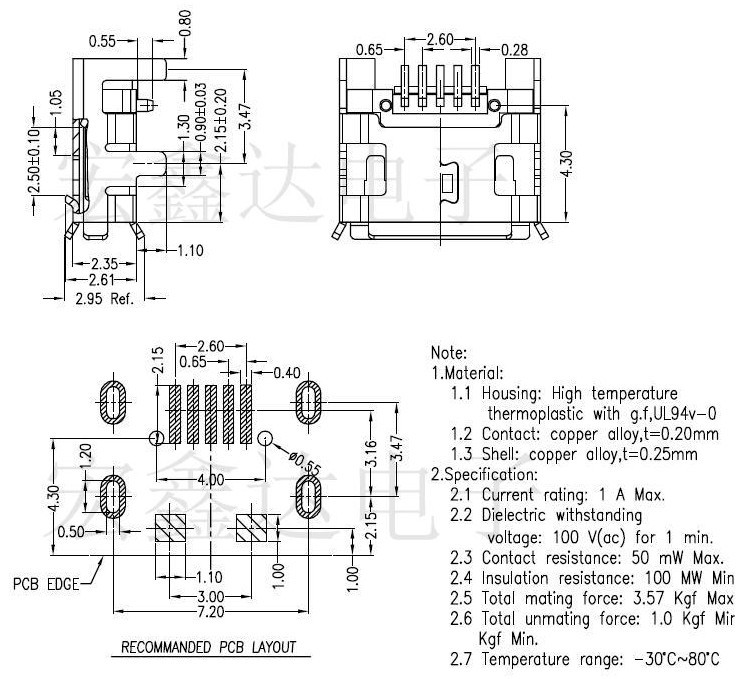
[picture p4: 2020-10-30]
mechanical/drawings/USB_Connector_2.jpg

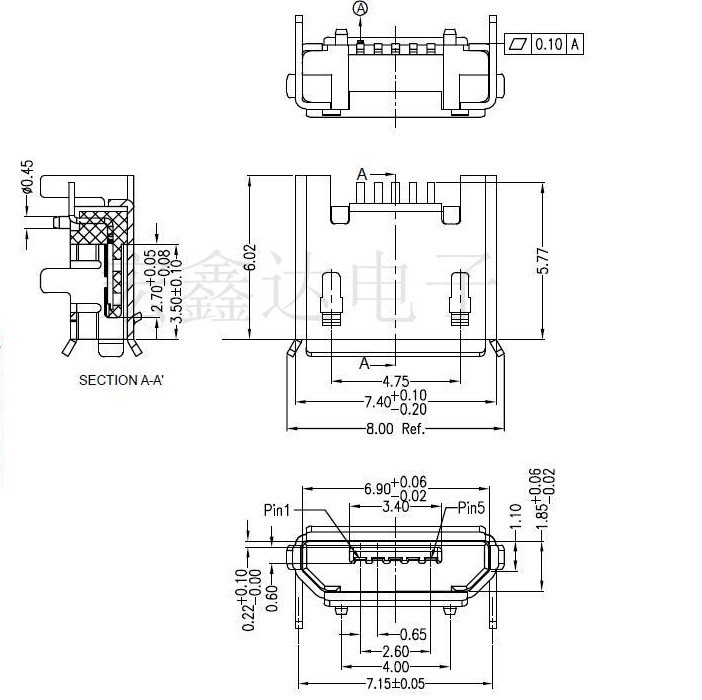
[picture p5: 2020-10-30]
mechanical/drawings/USB_Connector_1.jpg

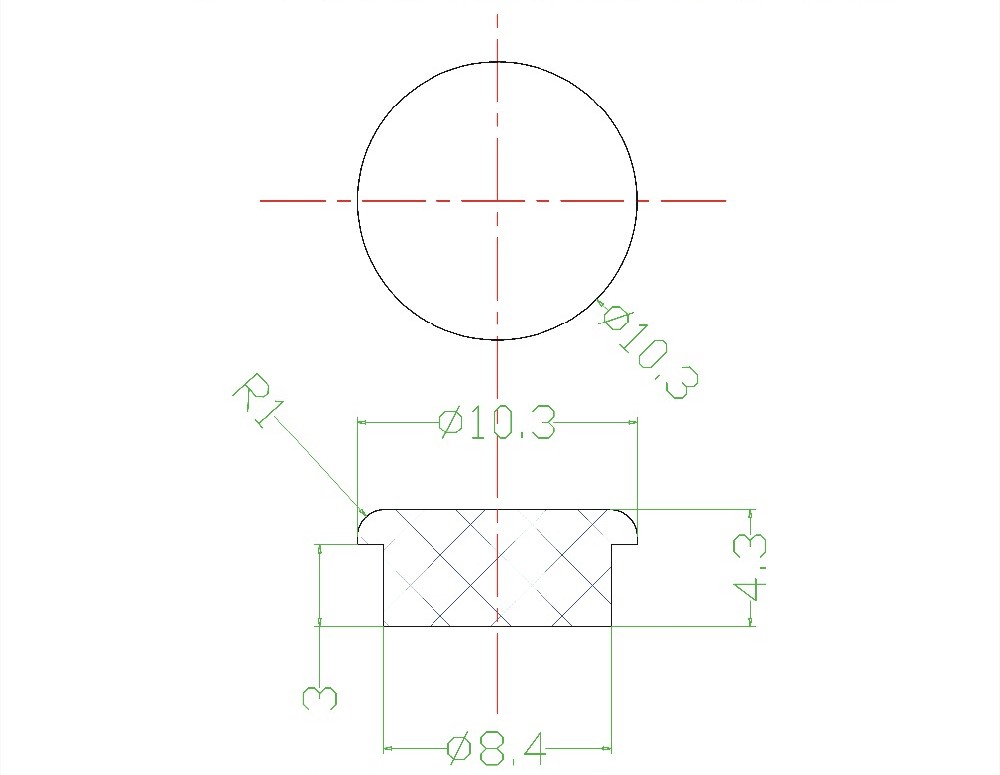
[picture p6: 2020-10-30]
mechanical/drawings/RubberPlug.jpg

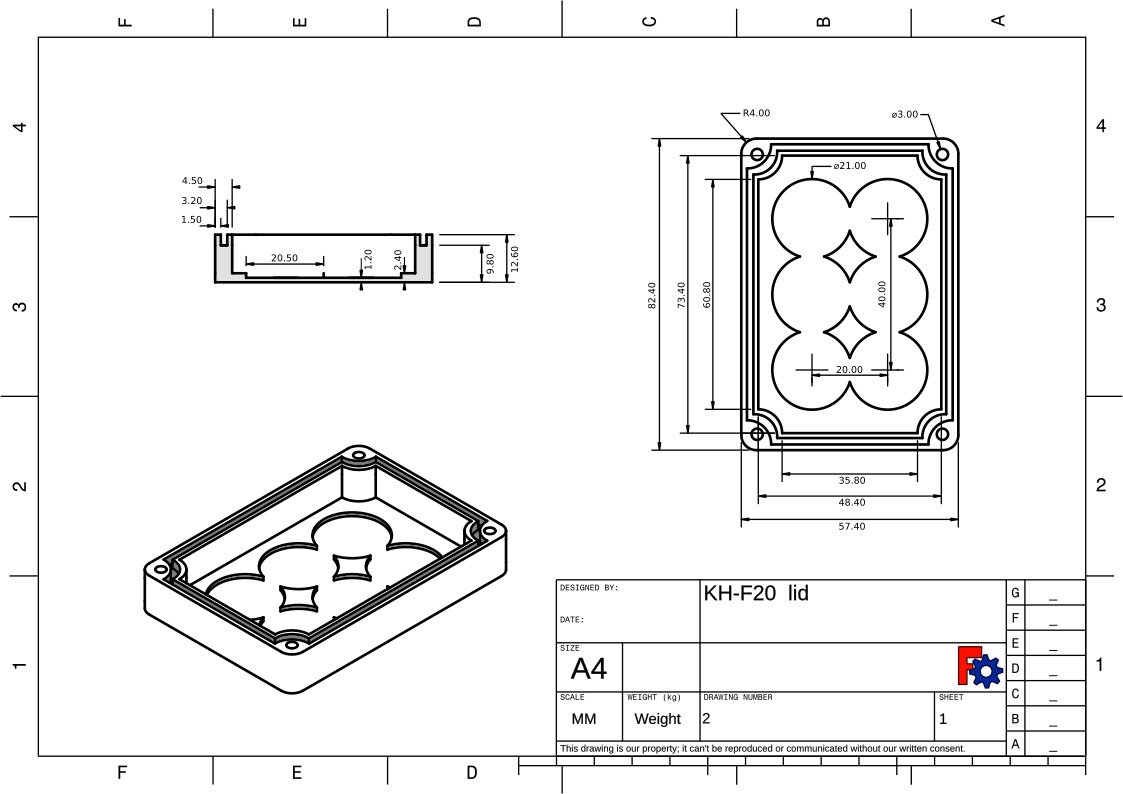
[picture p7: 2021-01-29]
mechanical/drawings/KH-F20_lid.jpg

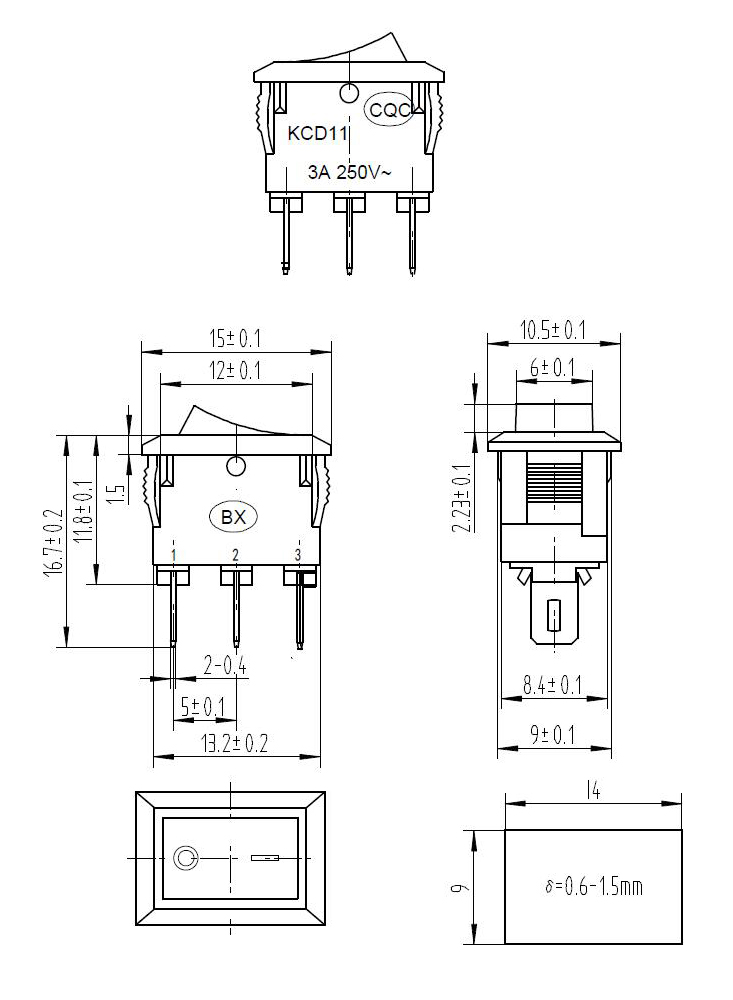
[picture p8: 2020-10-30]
mechanical/drawings/KCD11.jpg

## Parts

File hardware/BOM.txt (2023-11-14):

LocalTrack_rev1.3 ----------------------- 28.10.2020 (dd.mm.yyyy)

electronic and mechanical parts are available on aliexpress / lcsc
example links to these items are for information purposes, check
for offers with better prices and shipping details yourself

quantities specified in this file are pieces per single PCB

STM32F072C8T6 microcontroller --- 1pcs
W25N01GVZEIG 128MiB flash memory chip --- 1pcs

SIM28 GPS receiver module --- 1pcs
1575R-A 25x25x4mm GPS patch antenna 1575.42MHz --- 1pcs

MCP1700T-3302E/TT 3.3V LDO voltage regulator --- 1pcs
MCP73831T-2DCI single li-po cell charge controller IC --- 2pcs
SI2302 N-channel mosfet --- 4pcs
SI2301 P-channel mosfet --- 2pcs
IP4220CZ6 ESD protection diode --- 1pcs
ADXL345BCCZ MEMS accelerometer --- 1pcs
0805 (metric 2012) ceramic capacitor 10uF X5R 10% 16V --- 4pcs
0603 (metric 1608) ceramic capacitor 100nF X7R 10% 50V --- 9pcs
0603 (metric 1608) ceramic capacitor 18pF C0G 5% 50V --- 2pcs
0603 (metric 1608) resistor 100 kOhm 5% tolerance --- 6pcs
0603 (metric 1608) resistor 10 kOhm 5% tolerance --- 5pcs
0603 (metric 1608) resistor 1 kOhm 5% tolerance --- 6pcs
0603 (metric 1608) resistor 33 Ohm 5% tolerance --- 3pcs
(metric 5032) NX5032GA 8MHz crystal resonator --- 1pcs
0603 (metric 1608) LED RED --- 1pcs
0603 (metric 1608) LED GREEN --- 1pcs
0603 (metric 1608) LED BLUE --- 1pcs

5x1 male pin header, vertical, 2.54mm pitch --- 1pcs

noname? horizontal micro USB connector --- 1pcs
    https://www.aliexpress.com/item/32765504799.html

8.4mm diameter, 3mm length (without head) rubber plug --- 1pcs
    https://www.aliexpress.com/item/32974255931.html

KCD1-11 rocker switch --- 1pcs
    I recommend to have a waterproof cover as provided via link below
    https://aliexpress.com/item/1005001835611654.html

EHAO 3.7V 3000mAh li-po battery 103565 --- 1pcs
    https://www.aliexpress.com/item/32879938149.html

cyllindrical neodymium magnet 20mm diameter, 3mm height --- 6pcs
    these are glued on to removable lid, battery is then glued on top of that
    https://www.aliexpress.com/item/1005001531120300.html

KH-F20 plastic enclosure (search aliexpress for 85x58x33mm enclosure), no mounting ears, nontransparent lid --- 1pcs
    https://www.aliexpress.com/item/32894036224.html

M3 countersunk head screw, 14mm length (without head) --- 4 pcs
    these should be included together with KH-F20 enclosure from the seller

M3 screw, 4mm length (without head) --- 4pcs
    https://www.aliexpress.com/item/32599502547.html

---------------------------------------------------------------------------------------------------

List of Accessories:

charging micro USB cable (1A or more) with extra long 8mm plug --- 1pcs
    https://www.aliexpress.com/item/32898415553.html

USB charger with detachable cable, output current of 1A or more --- 1pcs
    https://aliexpress.com/item/1005002034160981.html

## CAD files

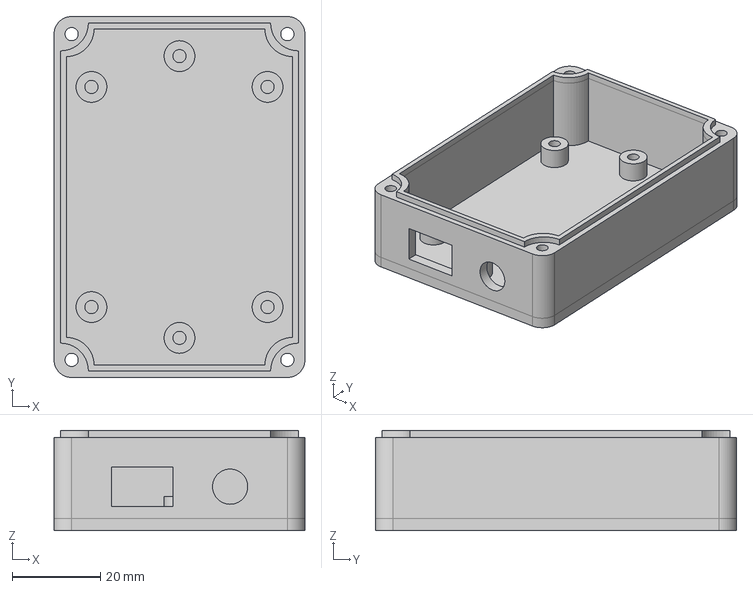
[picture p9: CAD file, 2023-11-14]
mechanical/KH-F20.FCStd
57.0 x 82.0 x 22.8 mm

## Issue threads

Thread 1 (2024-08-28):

featurerequest или needhelp синхронизация по времени выключателя и сегментов трека

mike1s, 2024-08-28:
Здравствуйте. Спасибо за разработку! Подскажите, пожалуйста. Колхожу устройство, панорамную камеру, в которой мне очень бы помогло не бороться с ленью если бы логгер заканчивал и начинал треки (или сегменты) ровно до секунды с выключателем (с фиксацией, можно дополнительным, вторые контакты включают интервальную съёмку на камерах), или хотя бы только начинал с уже предварительно включёным Гпс- модулем сразу готовым выдавать координаты, или только заканчивал но не выключал Гпс чтобы к следующему включению координаты были сразу, или хотя бы что- нибудь для автоматизированной синхронизации с фотками. Есть ли какие- нибудь простые возможности? Смдшки паяю.

krakrukra, 2024-08-31:
Извиняюсь за долгий ответ, просто уведомлений никаких не приходило. Случайно зашёл в репозиторий и увидел вопрос.
Я так понимаю речь идёт о том чтобы сделать такой режим где логгер всегда включён, но записывает маршрут только если нажат выключатель. С тем выключателем который уже встроен в устройство это не получится, он так стоит в схеме что может только включать или выключать питание. В принципе, если есть возможность, можно где-то в корпусе выпилить новую дырку под новый выключатель и проводами/проволокой подключить его к свободной ножке микроконтроллера и к земле. Тогда можно будет прописать в прошивке нужное поведение в соответствии с состоянием второго переключателя. Это наверное самый быстрый и простой вариант.
Ну а вообще у меня была раньше идея допилить какой-нибудь USB-serial интерфейс чтобы можно было в режиме реального времени ловить данные с логгера на компьютер/телефон по проводу USB, возможно передавать команды для включения/выключения итд. Если есть интерес то можно достать эту идею из небытия и всё-таки сделать, но это займёт довольно много времени и  будет не скоро

mike1s, 2024-09-01:
Понятно. Спасибо за ответ. Я ещё подумаю и позже напишу

Closed 2024-10-27.

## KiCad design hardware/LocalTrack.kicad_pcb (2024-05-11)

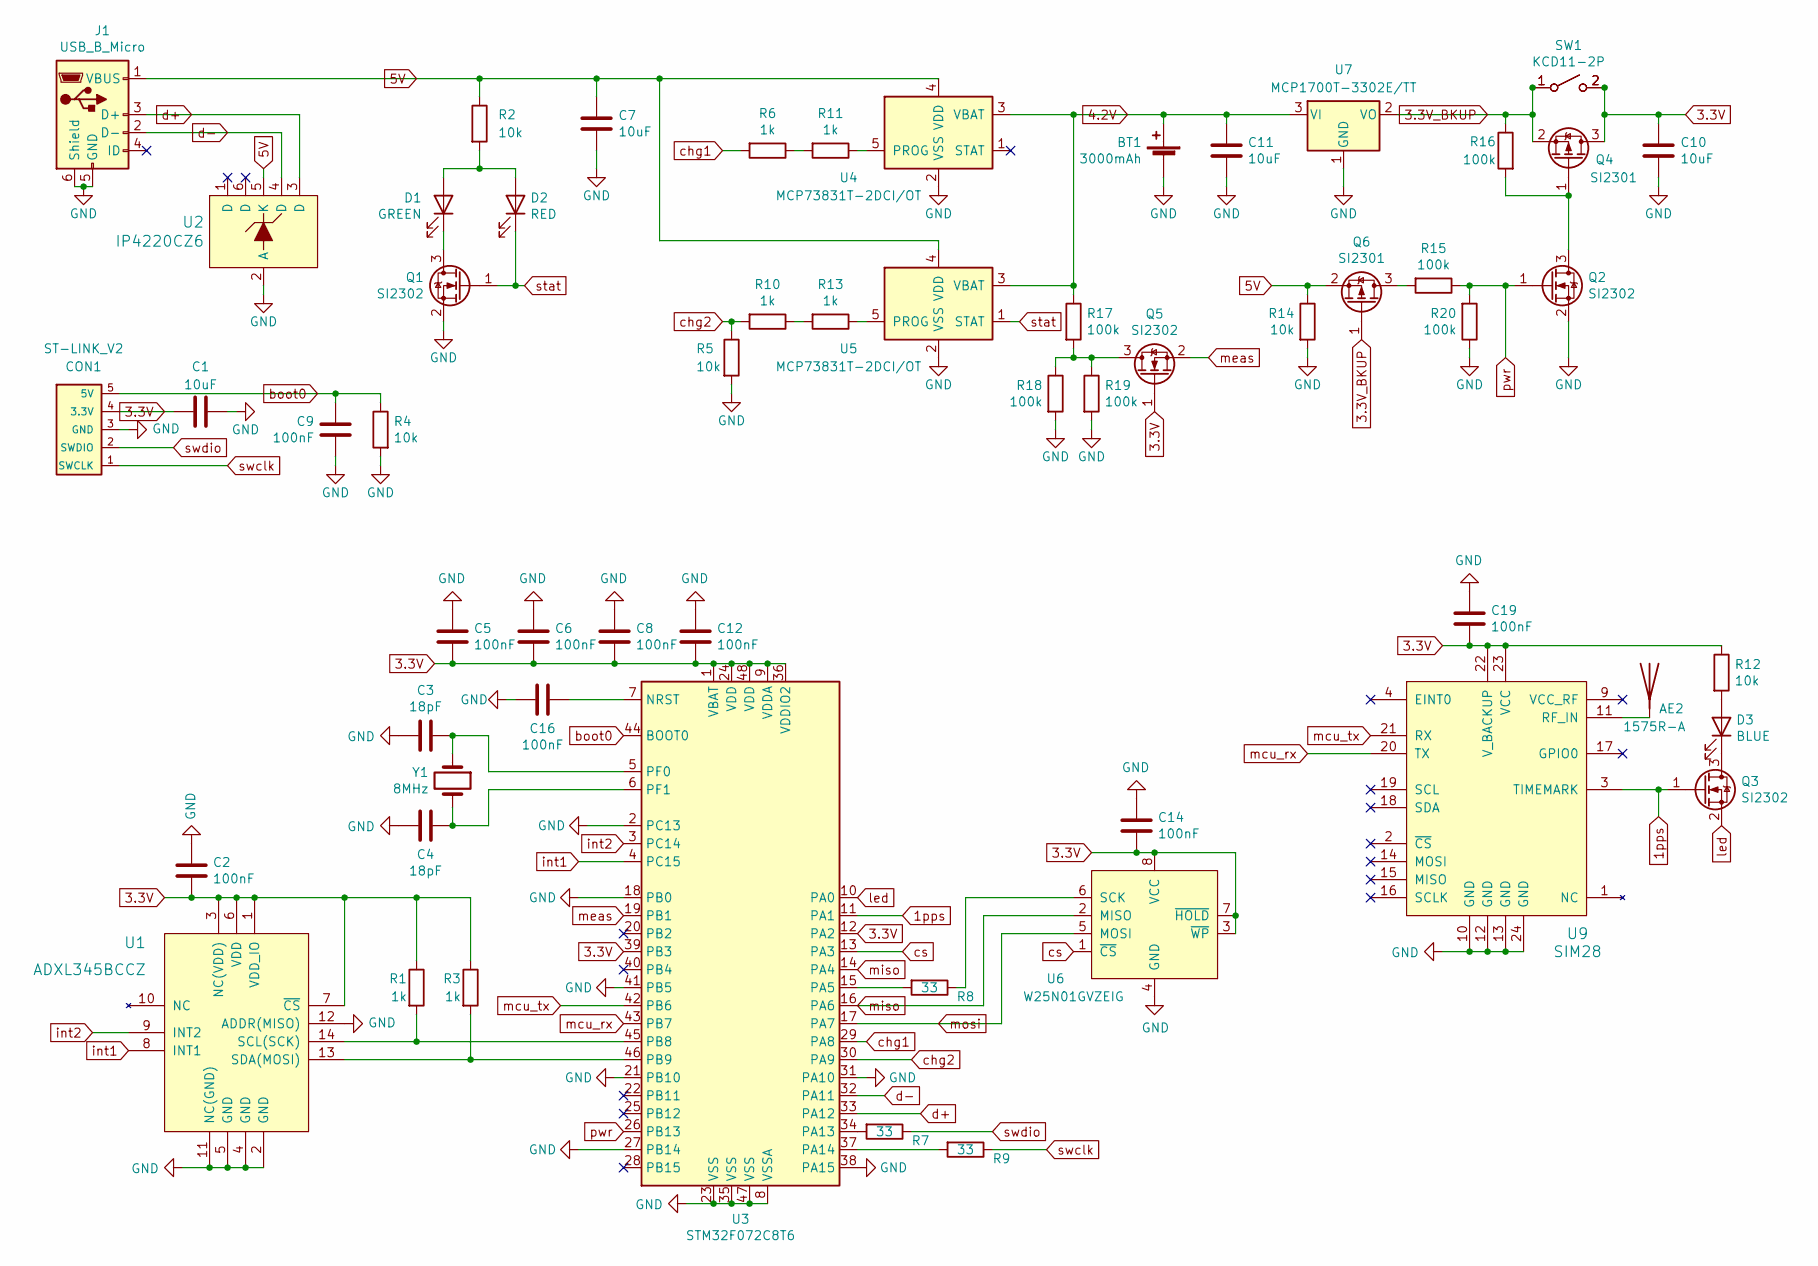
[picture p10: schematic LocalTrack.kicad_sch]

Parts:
AE2: 1575R-A
BT1: 3000mAh; JST_PH_B2B-PH-K_1x02_P2.00mm_Vertical
C1, C7, C10, C11: 10uF; C_0805_2012Metric
C2, C5, C6, C8, C9, C12, C14, C16, C19: 100nF; C_0603_1608Metric
C3, C4: 18pF; C_0603_1608Metric
CON1: ST-LINK_V2; PinHeader_1x05_P2.54mm_Vertical
D1: GREEN; LED_0603_1608Metric
D2: RED; LED_0603_1608Metric
D3: BLUE; LED_0603_1608Metric
J1: USB_B_Micro; MicroUSB_B
Q1, Q2, Q3, Q5: SI2302; SOT-23
Q4, Q6: SI2301; SOT-23
R1, R3, R6, R10, R11, R13: 1k; R_0603_1608Metric
R2, R4, R5, R12, R14: 10k; R_0603_1608Metric
R7, R8, R9: 33; R_0603_1608Metric
R15, R16, R17, R18, R19, R20: 100k; R_0603_1608Metric
SW1: KCD11-2P; KCD1-11
TP1: test pins; TestPins
U1: ADXL345BCCZ; LGA-14_3x5mm_P0.8mm_LayoutBorder1x6y
U2: IP4220CZ6; TSOP-6_1.65x3.05mm_P0.95mm
U3: STM32F072C8T6; LQFP-48_7x7mm_P0.5mm
U4, U5: MCP73831T-2DCI/OT; SOT-23-5
U6: W25N01GVZEIG; WSON-8_8x6mm
U7: MCP1700T-3302E/TT; SOT-23
U9: SIM28
Y1: 8MHz; Crystal_SMD_5032-2Pin_5.0x3.2mm

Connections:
1pps: Q3.1 (G), U3.11 (PA1), U9.3 (TIMEMARK)
3.3V: C1.1, C2.2, C5.2, C6.2, C8.2, C10.1, C12.2, C14.2, C19.2, CON1.4 (3.3V), Q4.3 (D), Q5.1 (G), R1.1, R3.1, R12.1, SW1.2 (B), TP1.2 (B), U1.1 (VDD_IO), U1.3 (NC(VDD)), U1.6 (VDD), U1.7 (~CS), U3.1 (VBAT), U3.9 (VDDA), U3.12 (PA2), U3.24 (VDD), U3.36 (VDDIO2), U3.39 (PB3), U3.48 (VDD), U6.3 (~WP), U6.7 (~HOLD), U6.8 (VCC), U9.22 (V_BACKUP), U9.23 (VCC)
3.3V_BKUP: Q4.2 (S), Q6.1 (G), R16.1, SW1.1 (A), TP1.1 (A), U7.2 (VO)
4.2V: BT1.1 (+), C11.1, R17.1, U4.3 (VBAT), U5.3 (VBAT), U7.3 (VI)
5V: C7.1, J1.1 (VBUS), Q6.2 (S), R2.1, R14.1, U2.5 (K), U4.4 (VDD), U5.4 (VDD)
GND: BT1.2 (-), C1.2, C2.1, C3.2, C4.2, C5.1, C6.1, C7.2, C8.1, C9.2, C10.2, C11.2, C12.1, C14.1, C16.2, C19.1, CON1.3 (GND), J1.5 (GND), J1.6 (Shield), Q1.2 (S), Q2.2 (S), R4.2, R5.2, R14.2, R18.2, R19.2, R20.1, U1.2 (GND), U1.4 (GND), U1.5 (GND), U1.11 (NC(GND)), U1.12 (ADDR(MISO)), U2.2 (A), U3.2 (PC13), U3.8 (VSSA), U3.18 (PB0), U3.21 (PB10), U3.23 (VSS), U3.27 (PB14), U3.31 (PA10), U3.35 (VSS), U3.38 (PA15), U3.41 (PB5), U3.47 (VSS), U4.2 (VSS), U5.2 (VSS), U6.4 (GND), U6.9 (GND), U7.1 (GND), U9.10 (GND), U9.12 (GND), U9.13 (GND), U9.24 (GND)
unnamed: AE2.1, U9.11 (RF_IN)
unnamed: C3.1, U3.5 (PF0), Y1.1
unnamed: C4.1, U3.6 (PF1), Y1.2
unnamed: C16.1, U3.7 (NRST)
unnamed: D1.1 (K), Q1.3 (D)
unnamed: D1.2 (A), D2.2 (A), R2.2
unnamed: D3.1 (K), Q3.3 (D)
unnamed: D3.2 (A), R12.2
unnamed: Q2.3 (D), Q4.1 (G), R16.2
unnamed: Q5.3 (D), R17.2, R18.1, R19.1
unnamed: Q6.3 (D), R15.2
unnamed: R1.2, U1.14 (SCL(SCK)), U3.45 (PB8)
unnamed: R3.2, U1.13 (SDA(MOSI)), U3.46 (PB9)
unnamed: R7.2, U3.34 (PA13)
unnamed: R8.1, U6.6 (SCK)
unnamed: R8.2, U3.15 (PA5)
unnamed: R9.2, U3.37 (PA14)
unnamed: R10.1, R13.2
unnamed: R11.1, U4.5 (PROG)
unnamed: R6.1, R11.2
unnamed: R13.1, U5.5 (PROG)
unnamed: U9.1 (NC), U9.5 (NC), U9.6 (NC), U9.7 (NC), U9.8 (NC)
boot0: C9.1, CON1.5 (5V), R4.1, U3.44 (BOOT0)
chg1: R6.2, U3.29 (PA8)
chg2: R5.1, R10.2, U3.30 (PA9)
cs: U3.13 (PA3), U6.1 (~CS)
d+: J1.3 (D+), U2.3 (D), U3.33 (PA12)
d-: J1.2 (D-), U2.4 (D), U3.32 (PA11)
int1: U1.8 (INT1), U3.4 (PC15)
int2: U1.9 (INT2), U3.3 (PC14)
led: Q3.2 (S), U3.10 (PA0)
mcu_rx: U3.43 (PB7), U9.20 (TX)
mcu_tx: U3.42 (PB6), U9.21 (RX)
meas: Q5.2 (S), U3.19 (PB1)
miso: U3.14 (PA4), U3.16 (PA6), U6.2 (MISO)
mosi: U3.17 (PA7), U6.5 (MOSI)
pwr: Q2.1 (G), R15.1, R20.2, U3.26 (PB13)
stat: D2.1 (K), Q1.1 (G), U5.1 (STAT)
swclk: CON1.1 (SWCLK), R9.1
swdio: CON1.2 (SWDIO), R7.1

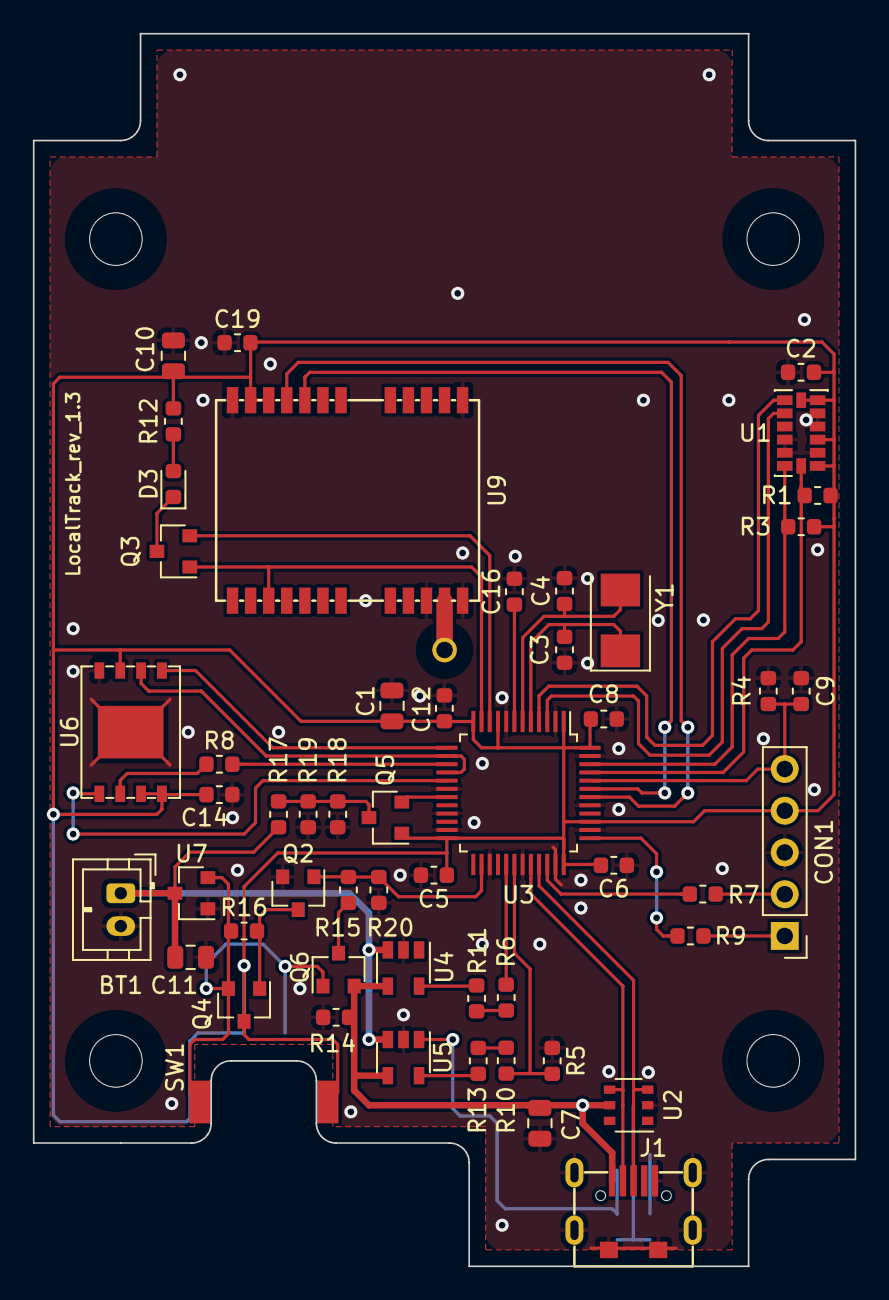
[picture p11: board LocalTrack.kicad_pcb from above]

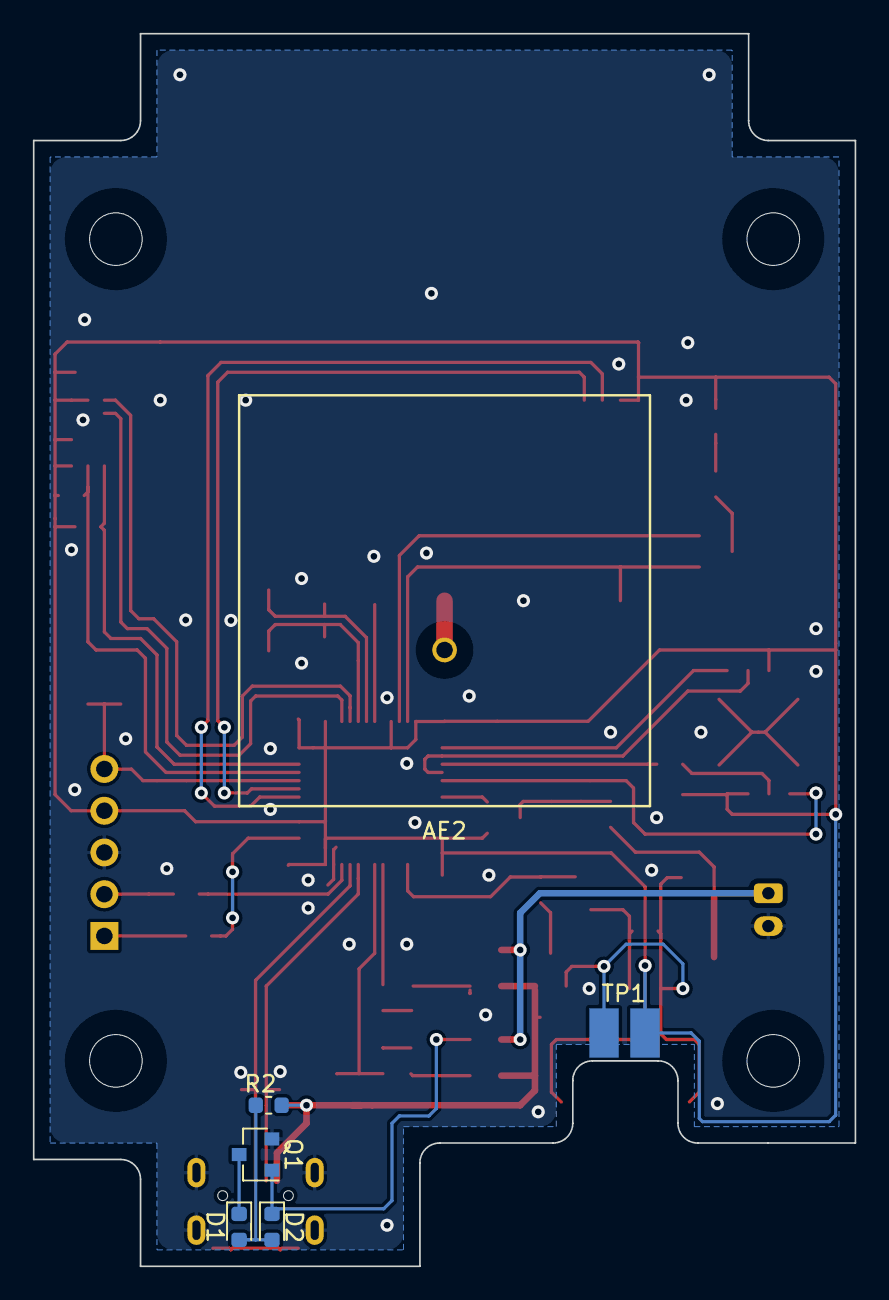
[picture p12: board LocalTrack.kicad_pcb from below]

Board: 2 copper layers, 50.0 x 75.0 mm, 59 parts (6 on the bottom side), 46 nets.

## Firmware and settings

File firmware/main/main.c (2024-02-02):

#include "../cmsis/stm32f0xx.h"
#include "peripherals.h"
#include "../fatfs/ff.h"
#include "../fatfs/diskio.h"
#include "../usb/usb.h"

//regular state check functions
static void sleepmodeCheck();
static void diskmodeCheck();
static void voltageCheck();
static void processNMEA();

//functions for processing of NMEA data
static void processGPRMC();
static void processGPGGA();
static void processGPGSA();
static char checkKeyword(char* referenceString);
static unsigned int readValue(unsigned int factor);
static void skipAfter(char symbol);

//functions for creating GPX output
static void startNewTrack();
static void stopCurrentTrack();
static void addTrackPoint();
static void appendGPXtext(char* text);
static void appendGPXvalue(int value, unsigned int divisor, unsigned int skipLimit);

//functions to write appropriate configuration values
static void readConfigFile();
static void setFixInterval(unsigned int newInterval);
static void setDateTime();

//other functions
static void MCUsleep();
static void verifyGPXfiles();
static void writeStatusFile();
static void enterBootloader();

//FATFS related global variables
static FATFS FATFSinfo;
static FIL FILinfo;
static FILINFO FILINFOinfo;
static unsigned int temp;//for storing general temporary values

//GPS logger related global variables
unsigned char NMEAbuffer[1024];//buffer for NMEA sentences received from SIM28
unsigned char GPXbuffer[1024];//buffer to temporarily store GPX data to be written in a file

//array to convert month of the year into number of days it contains (change 28 to 29 for leap years)
static unsigned char MonthToDays[12] = {31, 28, 31, 30, 31, 30, 31, 31, 30, 31, 30, 31};

LoggerInfo_TypeDef LoggerInfo =
  {
    .RMCdata =
    {
      .time = 0,
      .latitude = 0,
      .longitude = 0,
      .speed = 0,
      .course = 0,
      .date = 0,
      .dataStatus = 0,
      .mode = 0
    },
    
    .GGAdata =
    {
      .time = 0,
      .latitude = 0,
      .longitude = 0,
      .altitude = 0,
      .hdop = 5000,
      .numSatUsed = 0,
      .dataStatus = 0
    },
    
    .GSAdata =
    {
      .pdop = 5000,
      .hdop = 5000,
      .vdop = 5000,
      .fixType = 1 
    },
    
    .SupplyVoltage = 0,
    .BatteryVoltage = 0,
    .TrackFileOffset = 0,
    .NMEApointer = &NMEAbuffer[0],
    .UTCoffset = 0,
    .GPXsize = 0,
    .MaxNumSat = 0,
    .FileName  = {0},
    .TrackName = {0},
    .FixInterval = "PMTK220,1000",
    .ConfigFlags = 0
  };

//------------------------------------------------------------------------------------

int main()
{
  //clocks configuration  
  RCC->CFGR3 |= (1<<4);//I2C1 runs on system clock
  RCC->AHBENR |= (1<<19)|(1<<18)|(1<<17)|(1<<0);//enable GPIOA, GPOIB, GPIOC, DMA1 clocks
  RCC->APB1ENR |= (1<<28)|(1<<21)|(1<<5)|(1<<1)|(1<<0);//enable PWR, I2C1, TIM2, TIM3, TIM7 clocks
  RCC->APB2ENR |= (1<<14)|(1<<12)|(1<<9)|(1<<0);//enable USART1, SPI1, ADC_interface, SYSCFG clocks
  ADC1->CFGR2 = (1<<30);//ADC1 clock = PCLK / 2
  RCC->CSR |= (1<<0);//enable LSI clock
  
  //SCB configuration
  SCB->SCR |= (1<<2);//set stop mode as default low power mode
  
  //ports configuration
  GPIOB->MODER |= (1<<19)|(1<<17)|(1<<15)|(1<<13)|(1<<3)|(1<<2);//PB6, PB7, PB8, PB9 are in alternate function mode, PB1 is analog input
  GPIOB->AFR[1] |= (1<<4)|(1<<0);//PB8, PB9 are I2C1; PB6, PB7 are USART1
  SYSCFG->CFGR1 |= (1<<10)|(1<<9);//remap USART1 DMA requests to channels 4 and 5
  
  //EXTI configuration
  SYSCFG->EXTICR[3] = (1<<13);//EXTI line 15 is connected to GPIOC
  EXTI->IMR = (1<<20)|(1<<15);//enable EXTI lines 20, 15
  EXTI->RTSR = (1<<20)|(1<<15);//EXTI lines 20, 15 are triggered at rising edge
  NVIC_EnableIRQ(7);//enable ADXL345 activity interrupt
  
  //USART1 configuration
  //1 start bit, 8 bit transfer (least significant bit first), 1 stop bit; oversampling by 16;
  USART1->CR3 = (1<<12);//disable overrun detection, disable DMA requests
  USART1->BRR = 833;//set baudrate to 9600
  USART1->CR1 = (1<<3)|(1<<2)|(1<<0);//enable USART1; send idle character
  
  //I2C1 configuration
  I2C1->TIMINGR = (0x0<<28)|(0x3<<20)|(0x1<<16)|(0x3<<8)|(0x9<<0);//PRESC=0x0, SCLDEL=0x3, SDADEL=0x1, SCLH=0x3, SCLL=0x9 (400kHz clock)
  I2C1->CR1 |= (1<<0);//enable I2C1
  
  //ADC1 configuration
  ADC1->CR = (1<<31);//start ADC1 calibration
  while(ADC1->CR & (1<<31));//wait until calibration is complete
  __DSB();//make sure all outstanding memory transfers are over
  ADC1->CR = (1<<0);//enable ADC1
  while( !(ADC1->ISR & (1<<0)) );//wait until ADC1 is ready
  ADC1->CFGR1 = (1<<16)|(1<<2);//discontinuous conversion mode, keep old data on overrun, scan backwards
  ADC1->SMPR = (1<<2)|(1<<1)|(1<<0);//use 239.5 ADC cycles of sample time (59.875us at PCLK = 8Mhz)
  ADC->CCR = (1<<22);//enable reference voltage for ADC1
  ADC1->CHSELR = (1<<17)|(1<<9);//enable Vref and ADC_IN9 channels for ADC1
  ADC1->CR = (1<<2)|(1<<0);//start new ADC conversion
  
  //RTC configuration
  while( !(RCC->CSR & (1<<1)) );//wait until LSI is ready
  PWR->CR |= (1<<8);//enable access to RTC
  RCC->BDCR |= (1<<16);//reset RTC peripheral
  RCC->BDCR &= ~(1<<16);//deassert RTC reset
  RCC->BDCR |= (1<<15)|(1<<9);//enable clock for RTC peripheral, use LSI
  RTC->WPR = 0xCA;//disable write-protection of RTC registers
  RTC->WPR = 0x53;//disable write-protection of RTC registers
  RTC->ISR |= (1<<7);//enter RTC initialization mode
  while( !(RTC->ISR & (1<<6)) );//wait until RTC configuration can be changed
  RTC->PRER = (124<<16)|(319<<0);//PREDIV_A + 1 = 125, PREDIV_S + 1 = 320; 40kHz clock expected
  RTC->ISR &= ~(1<<7);//exit RTC initialization mode
  NVIC_EnableIRQ(2);//enable RTC wakeup timer interrupt
  
  __enable_irq();//enable interrupts globally
  
//------------------------------------------------------------------------------------
  
  restart_tim2(5);//have a startup delay of 5ms for W25N01GVZEIG
  while(TIM2->CR1 & (1<<0)) voltageCheck();//while timer runs out, keep measuring and supply voltage
  
  //if battery is discharged, stop and wait until battery is recharged up to minimum working level
  if(LoggerInfo.SupplyVoltage < 290000) while(LoggerInfo.SupplyVoltage < 300000) voltageCheck();
  
  if( f_mount(&FATFSinfo, "0:", 1) == FR_OK )//if f_mount() was successful
    { 
      verifyGPXfiles();//append GPX track and file terminations to all GPX files that do not have it (eg. because of poweroff)
      readConfigFile();//run configuration commands from config.txt
      sim28_init();//configure SIM28, ensure it is in a known state
    }
  else//if no valid FAT was found
    {
      disk_initialize(0);//initialize the flash storage for MSD use
      sim28_init();//configure SIM28, ensure it is in a known state
      sim28_sleep();//tell SIM28 to enter sleepmode, since there is nowhere to store the data
    }
  
  restart_tim3(300);//set sleepmode timer to 5 minutes
  adxl_init();//initialize ADXL345
  
  while(1)
    { 
      voltageCheck();//measure battery and supply voltages, save results in RAM
      diskmodeCheck();//if USB cable is connected go to diskmode
      sleepmodeCheck();//if sleepmode timer has run out, go to sleepmode
      processNMEA();//if new 512 byte block of NMEA data is received, process messages inside
      garbage_collect();//if some block in flash became invalid, erase it
    }
  
  NVIC_SystemReset();
  return 0;
}

//------------------------------------------------------------------------------------

//if necessary, enter sleep mode (or low battery mode)
static void sleepmodeCheck()
{
  if(GPIOC->IDR & (1<<15))//if activity was detected
    {
      restart_tim3(120);//reset sleepmode timer to 2 minutes
      adxl_clear();//clear activity signal
    }
  
  //if sleepmode timer had ran out (no activity or speed detected), or if battery is discharged
  if( !(TIM3->CR1 & (1<<0)) || (LoggerInfo.SupplyVoltage < 290000) )
    {
      stopCurrentTrack();//if some track file was being written, add track termination
      sim28_sleep();//tell SIM28 to enter sleepmode
      adxl_clear();//clear activity signal, so that MCU can wake up on new activity detection
      MCUsleep();//enter MCU sleep mode
      while(LoggerInfo.SupplyVoltage < 300000) voltageCheck();//wait until battery is recharged up to minimum working level
      
      if( f_mount(&FATFSinfo, "0:", 1) == FR_OK )//if valid filesystem is available
	{
	  sim28_init();//wake up SIM28
	  restart_tim3(300);//set sleepmode timer to 5 minutes
	}
      else//if filesystem can not be mounted
	{
	  //keep SIM28 in sleep mode
	  restart_tim3(60);//set sleepmode timer to 1 minute
	}
    }
  
  return;
}

//if USB cable is connected, ignore incoming NMEA data and only act as USB disk
static void diskmodeCheck()
{
  if(GPIOB->IDR & (1<<13))//if VBUS voltage is detected
    { 
      sim28_sleep();//tell SIM28 to enter sleepmode
      stopCurrentTrack();//if some track file was being written, add track and file termination
      writeStatusFile();//take a snapshot of current status values, save them into a text file
      
      FLASH->ACR = (1<<4)|(1<<0);//enable prefetch buffer, insert 1 wait state for flash read access (needed because SYSCLK will be 48MHz)
      
      RCC->CFGR |= (1<<20)|(1<<16);//derive PLL clock from HSE, multiply HSE by 6 (8MHz * 6 = 48MHz)
      RCC->CR |= (1<<24);//enable PLL
      while( !(RCC->CR & (1<<25)) );//wait until PLL is ready
      RCC->CFGR = (1<<20)|(1<<16)|(1<<1);//set PLL as system clock
      while( !((RCC->CFGR & 0x0F) == 0b1010) );//wait until PLL is used as system clock
      
      if(LoggerInfo.ConfigFlags & (1<<2)) enterBootloader();
      else usb_init();//initialize USB peripheral
      while(GPIOB->IDR & (1<<13)) usb_handler();//while USB cable is plugged in, act as flash disk only
      
      //once USB cable was disconnected, decrease current draw to 83mA, disable USB peripheral
      GPIOA->MODER &= ~((1<<18)|(1<<16));//disconnect chg1 and chg2 lines from ground
      RCC->APB1RSTR |=  (1<<23);//reset USB peripheral
      
      RCC->CFGR = (1<<20)|(1<<16)|(1<<0);//set HSE as system clock
      while( !((RCC->CFGR & 0x0F) == 0b0101) );//wait until HSE is used as system clock
      RCC->CR &= ~(1<<24);//disable PLL
      
      FLASH->ACR = 0;//disable prefetch buffer, have no wait state for flash read access (because SYSCLK will be 8MHz)
      
      if( f_mount(&FATFSinfo, "0:", 1) == FR_OK )//reinitialize FATFSinfo structure, in case the filesystem was altered during USB diskmode
	{	
	  readConfigFile();//load new configuration from config.txt
	  sim28_init();//wake up SIM28
	  restart_tim3(300);//set sleepmode timer to 5 minutes
	}
      else//if filesystem can not be mounted
	{
	  //keep SIM28 in sleepmode
	  restart_tim3(60);//set sleepmode timer to 1 minute  
	}
      
    }
  
  return;
}

//measure battery and supply voltages, save results in RAM
static void voltageCheck()
{
  if(ADC1->ISR & (1<<2))//if ADC conversion is complete
    {
      //if ADC_IN9 channel was converted (end of sequence), compute battery voltage
      if(ADC1->ISR & (1<<3)) LoggerInfo.BatteryVoltage = ( LoggerInfo.SupplyVoltage * ADC1->DR ) / 1365;// Vbat / 3 = Vdd / 2^12 * Vmeas       
      //if Vref channel was converted (sequence not over yet), compute MCU supply voltage
      else LoggerInfo.SupplyVoltage = ( 330000 * *((unsigned short*) 0x1FFFF7BA) ) / ADC1->DR;// Vdd = 3.3V * VREFINT_CAL / VREFINT_DATA
      
      ADC1->ISR = (1<<3)|(1<<2)|(1<<1);//clear EOSEQ, EOC, EOSMP flags
      ADC1->CR = (1<<2)|(1<<0);//start new ADC conversion
    }
  
  return;
}

//------------------------------------------------------------------------------------

//process a newly received 512 byte block of NMEA data
static void processNMEA()
{
  unsigned char* whereToStop; //used to find messageCount value
  unsigned char* whereToCheck;//used to find messageCount value
  unsigned char  messageCount = 0;//holds how many NMEA messages to process
  
  //if a complete 512 byte block was received, clear appropriate DMA flag and remember where the end of this block is
       if(DMA1->ISR & (1<<18)) {DMA1->IFCR = (1<<18); whereToStop = &NMEAbuffer[512];}
  else if(DMA1->ISR & (1<<17)) {DMA1->IFCR = (1<<17); whereToStop = &NMEAbuffer[0];}  
  else return;//if there is no new block to process, do nothing and exit
  
  //find how many messages are to be processed
  whereToCheck = LoggerInfo.NMEApointer;//start searching for message terminations at NMEApointer
  while(whereToCheck != whereToStop)//keep going until the end of newly received block is reached
    {
      if(*whereToCheck == 0x0A) messageCount++;
      
      //move to next character in NMEAbuffer[]
      if(whereToCheck < &NMEAbuffer[1023]) whereToCheck++;
      else whereToCheck = &NMEAbuffer[0];
    }
  
  
  LoggerInfo.GPXsize = 0;//start writing new processed data at the beginning of GPXbuffer[]
  while(messageCount)//keep going until all messages in the buffer were processed
    {
           if( checkKeyword("$GPRMC") ) processGPRMC();//interpret the message and write correct values into RMCdata structure
      else if( checkKeyword("$GPGGA") ) processGPGGA();//interpret the message and write correct values into GGAdata structure
      else if( checkKeyword("$GPGSA") ) processGPGSA();//interpret the message and write correct values into GSAdata structure
      else                              skipAfter(0x0A);//if message is not recognized, skip to the next one
      
      //if last received GPRMC and GPGGA messages are valid and have the same timestamp
      if( ((LoggerInfo.RMCdata).dataStatus = 1) && ((LoggerInfo.GGAdata).dataStatus == 1) && ((LoggerInfo.RMCdata).time == (LoggerInfo.GGAdata).time) )
	{
	  if(LoggerInfo.TrackName[0] == 0) startNewTrack();//if there is no current track, start a new one
	  //add new trackpoint to GPXbuffer[], unless it has 0,0 coordinates
	  if( (LoggerInfo.RMCdata).longitude || (LoggerInfo.RMCdata).latitude ) addTrackPoint();
	  
	  (LoggerInfo.RMCdata).dataStatus = 0;//set RMC dataStatus to invalid, so the message is not used again
	  (LoggerInfo.GGAdata).dataStatus = 0;//set GGA dataStatus to invalid, so the message is not used again
	}
      
      messageCount--;//one more NMEA message was processed
    }
  
  
  if(LoggerInfo.GPXsize)//if there is a need to save some data into a file
    {
      //save all the new processed data to a GPX file
      if( f_open(&FILinfo, (char*) &LoggerInfo.FileName, FA_OPEN_APPEND | FA_WRITE) == FR_OK )
	{
	  f_write(&FILinfo, (void*) &GPXbuffer, LoggerInfo.GPXsize, &temp);
	  f_close(&FILinfo);
	}
    }
  
  return;
}

//fill RMCdata structure in RAM from GPRMC message
static void processGPRMC()
{
  skipAfter(',');//move to UTC time field, read the value
  (LoggerInfo.RMCdata).time = readValue(1000);
  
  skipAfter(',');//move to data status field, 'A' means data valid
  if(*LoggerInfo.NMEApointer == 'A') (LoggerInfo.RMCdata).dataStatus = 1;
  else                               (LoggerInfo.RMCdata).dataStatus = 0;
  
  skipAfter(',');//move to latitude field, read the value, convert it to decimal degrees
  (LoggerInfo.RMCdata).latitude = readValue(100000);//value was read in this format DDMMMMMMM (in units of degree, minute/10^5)
  (LoggerInfo.RMCdata).latitude = ((LoggerInfo.RMCdata).latitude / 10000000) * 10000000 + (((LoggerInfo.RMCdata).latitude % 10000000) * 10) / 6;
  
  skipAfter(',');//move to north/south field, add negative sign in case of south latitude
  if(*LoggerInfo.NMEApointer == 'S') (LoggerInfo.RMCdata).latitude = -(LoggerInfo.RMCdata).latitude;
  
  skipAfter(',');//move to longitude field, read the value, convert it to decimal degrees
  (LoggerInfo.RMCdata).longitude = readValue(100000);//value was read in this format DDDMMMMMMM (in units of degree, minute/10^5)
  (LoggerInfo.RMCdata).longitude = ((LoggerInfo.RMCdata).longitude / 10000000) * 10000000 + (((LoggerInfo.RMCdata).longitude % 10000000) * 10) / 6;
  
  skipAfter(',');//move to east/west field, add negative sign in case of west longitude
  if(*LoggerInfo.NMEApointer == 'W') (LoggerInfo.RMCdata).longitude = -(LoggerInfo.RMCdata).longitude;
  
  skipAfter(',');//move to speed over ground field, read the value, convert it to meters per second
  (LoggerInfo.RMCdata).speed = readValue(1000);//value was read in this format NNNNNNNNN (in units of knot/10^3)
  (LoggerInfo.RMCdata).speed = ((LoggerInfo.RMCdata).speed * 514) / 1000;
  
  skipAfter(',');//move to course over ground field, read the value
  (LoggerInfo.RMCdata).course = readValue(100);
  
  skipAfter(',');//move to date field, read the value
  (LoggerInfo.RMCdata).date = readValue(1);
  
  skipAfter(',');//move to magnetic variation field
  skipAfter(',');//move to east/west field
  
  skipAfter(',');//move to GPS mode field, read the value
       if(*LoggerInfo.NMEApointer == 'A') (LoggerInfo.RMCdata).mode = 1;
  else if(*LoggerInfo.NMEApointer == 'D') (LoggerInfo.RMCdata).mode = 2;
  else                                    (LoggerInfo.RMCdata).mode = 0;
  
  skipAfter(0x0A);//skip to the next command
  return;
}

//fill GGAdata structure in RAM from GPGGA message
static void processGPGGA()
{
  skipAfter(',');//move to UTC time field, read the value
  (LoggerInfo.GGAdata).time = readValue(1000);
  
  skipAfter(',');//move to latitude field, read the value, convert it to decimal degrees
  (LoggerInfo.GGAdata).latitude = readValue(100000);//value was read in this format DDMMMMMMM (in units of degree, minute/10^5)
  (LoggerInfo.GGAdata).latitude = ((LoggerInfo.GGAdata).latitude / 10000000) * 10000000 + (((LoggerInfo.GGAdata).latitude % 10000000) * 10) / 6;
  
  skipAfter(',');//move to north/south field, add negative sign in case of south latitude
  if(*LoggerInfo.NMEApointer == 'S') (LoggerInfo.GGAdata).latitude = -(LoggerInfo.GGAdata).latitude;
  
  skipAfter(',');//move to longitude field, read the value, convert it to decimal degrees
  (LoggerInfo.GGAdata).longitude = readValue(100000);//value was read in this format DDDMMMMMMM (in units of degree, minute/10^5)
  (LoggerInfo.GGAdata).longitude = ((LoggerInfo.GGAdata).longitude / 10000000) * 10000000 + (((LoggerInfo.GGAdata).longitude % 10000000) * 10) / 6;
  
  skipAfter(',');//move to east/west field, add negative sign in case of west longitude
  if(*LoggerInfo.NMEApointer == 'W') (LoggerInfo.GGAdata).longitude = -(LoggerInfo.GGAdata).longitude;
  
  skipAfter(',');//move to data status field; '1', '2' or '6' means data valid
       if(*LoggerInfo.NMEApointer == '1') (LoggerInfo.GGAdata).dataStatus = 1;
  else if(*LoggerInfo.NMEApointer == '2') (LoggerInfo.GGAdata).dataStatus = 1;
  else if(*LoggerInfo.NMEApointer == '6') (LoggerInfo.GGAdata).dataStatus = 1;
  else                                    (LoggerInfo.GGAdata).dataStatus = 0;
  
  skipAfter(',');//move to sattelites used field, read the value; update maximum sattelites value if necessary
  (LoggerInfo.GGAdata).numSatUsed = readValue(1);
  if( (LoggerInfo.GGAdata).numSatUsed > LoggerInfo.MaxNumSat ) LoggerInfo.MaxNumSat = (LoggerInfo.GGAdata).numSatUsed;
  
  skipAfter(',');//move to hdop field, read the value
  (LoggerInfo.GGAdata).hdop = readValue(100);
  
  skipAfter(',');//move to MSL altitude field, read the value
  (LoggerInfo.GGAdata).altitude = readValue(1000);
  
  skipAfter(0x0A);//skip to the next command
  return;
}

//fill GSAdata structure in RAM from GPGSA message
static void processGPGSA()
{
  skipAfter(',');//move to mode 1 field, do nothing
  
  skipAfter(',');//move to mode 2 field; '1' means fix not availabe, '2' means 2D fix, '3' means 3D fix
       if(*LoggerInfo.NMEApointer == '2') (LoggerInfo.GSAdata).fixType = 2;
  else if(*LoggerInfo.NMEApointer == '3') (LoggerInfo.GSAdata).fixType = 3;
  else                                    (LoggerInfo.GSAdata).fixType = 1;
  
  skipAfter(',');//move to sattelite used field  1, do nothing
  skipAfter(',');//move to sattelite used field  2, do nothing
  skipAfter(',');//move to sattelite used field  3, do nothing
  skipAfter(',');//move to sattelite used field  4, do nothing
  skipAfter(',');//move to sattelite used field  5, do nothing
  skipAfter(',');//move to sattelite used field  6, do nothing
  skipAfter(',');//move to sattelite used field  7, do nothing
  skipAfter(',');//move to sattelite used field  8, do nothing
  skipAfter(',');//move to sattelite used field  9, do nothing
  skipAfter(',');//move to sattelite used field 10, do nothing
  skipAfter(',');//move to sattelite used field 11, do nothing
  skipAfter(',');//move to sattelite used field 12, do nothing
  
  skipAfter(',');//move to pdop field, read the value
  (LoggerInfo.GSAdata).pdop = readValue(100);
  
  skipAfter(',');//move to hdop field, read the value
  (LoggerInfo.GSAdata).hdop = readValue(100);
  
  skipAfter(',');//move to vdop field, read the value
  (LoggerInfo.GSAdata).vdop = readValue(100);
  
  skipAfter(0x0A);//skip to the next command
  return;
}

//if referenceString is found at LoggerInfo.NMEApointer, return 1 and move to the next keyword
static char checkKeyword(char* referenceString)
{
  unsigned char* whereToCheck = LoggerInfo.NMEApointer;
  
  //keep comparing characters until the end of reference string
  while(*referenceString)
    {
      //if a mismatch is found, stop the function and return 0
      if( *whereToCheck != *referenceString ) return 0;
      referenceString++;//move to next character in keyword
      
      //move to next character in NMEAbuffer[]
      if(whereToCheck < &NMEAbuffer[1023]) whereToCheck++;
      else whereToCheck = &NMEAbuffer[0];
    }
  
  //if requested keyword was actually found, move NMEApointer to next keyword
  LoggerInfo.NMEApointer = whereToCheck;
  return 1;
}
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

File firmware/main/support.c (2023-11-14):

#include "../cmsis/stm32f0xx.h"

extern int main();
extern void dma_handler() __attribute__((interrupt));

static void startup();
static inline void initialize_data(unsigned int* from, unsigned int* data_start, unsigned int* data_end) __attribute__((always_inline));
static inline void initialize_bss(unsigned int* bss_start, unsigned int* bss_end) __attribute__((always_inline));

static void default_handler() __attribute__((interrupt));
static void rtc_handler() __attribute__((interrupt));
static void exti4_15() __attribute__((interrupt));

//these symbols are declared in the linker script
extern unsigned int __data_start__;//start of .data section in RAM
extern unsigned int __data_end__;//end of .data section in RAM
extern unsigned int __bss_end__;//end of .bss section in RAM
extern unsigned int __text_end__;//end of .text section in ROM

void* vectorTable[48] __attribute__(( section(".vectab,\"a\",%progbits@") )) =
  {
    (void*)0x20003FFC,//initial main SP value (16kB RAM size)
    (void*)&startup,//reset vector
    (void*)&default_handler,//NMI
    (void*)&default_handler,//HardFault
    (void*)0x00000000,//reserved
    (void*)0x00000000,//reserved
    (void*)0x00000000,//reserved
    (void*)0x00000000,//reserved
    (void*)0x00000000,//reserved
    (void*)0x00000000,//reserved
    (void*)0x00000000,//reserved
    (void*)&default_handler,//SVCall
    (void*)0x00000000,//reserved
    (void*)0x00000000,//reserved
    (void*)&default_handler,//PendSV
    (void*)&default_handler,//SysTick
    (void*)0x00000000,//IRQ0
    (void*)0x00000000,//IRQ1
    (void*)&rtc_handler,//IRQ2
    (void*)0x00000000,//IRQ3
    (void*)0x00000000,//IRQ4
    (void*)0x00000000,//IRQ5
    (void*)0x00000000,//IRQ6
    (void*)&exti4_15,//IRQ7
    (void*)0x00000000,//IRQ8
    (void*)0x00000000,//IRQ9
    (void*)&dma_handler,//IRQ10
    (void*)0x00000000,//IRQ11
    (void*)0x00000000,//IRQ12
    (void*)0x00000000,//IRQ13
    (void*)0x00000000,//IRQ14
    (void*)0x00000000,//IRQ15
    (void*)0x00000000,//IRQ16
    (void*)0x00000000,//IRQ17
    (void*)0x00000000,//IRQ18
    (void*)0x00000000,//IRQ19
    (void*)0x00000000,//IRQ20
    (void*)0x00000000,//IRQ21
    (void*)0x00000000,//IRQ22
    (void*)0x00000000,//IRQ23
    (void*)0x00000000,//IRQ24
    (void*)0x00000000,//IRQ25
    (void*)0x00000000,//IRQ26
    (void*)0x00000000,//IRQ27
    (void*)0x00000000,//IRQ28
    (void*)0x00000000,//IRQ29
    (void*)0x00000000,//IRQ30
    (void*)0x00000000 //IRQ31
  };

//copies initialized static variable values from ROM to RAM
static inline void initialize_data(unsigned int* from, unsigned int* data_start, unsigned int* data_end)
{
  while(data_start < data_end)
    {
      *data_start = *from;
      data_start++;
      from++;
    }
}

//writes to zero uninitialized static variable values in RAM
static inline void initialize_bss(unsigned int* bss_start, unsigned int* bss_end)
{
  while(bss_start < bss_end)
    {
      *bss_start = 0x00000000U;
      bss_start++;
    }
}

//the very first function that the CPU will run
static void startup()
{
  RCC->AHBENR |= (1<<17);//enable GPIOA clock
  GPIOA->MODER |= (1<<15)|(1<<13)|(1<<11)|(1<<6);//PA5, PA6, PA7 are in alternate function mode (SPI1); PA3 is output
  GPIOA->BSRR = (1<<3);//pull PA3 high (SPI1 CS output)
  
  RCC->CR |= (1<<19)|(1<<16);//enable HSE clock, clock security system
  
  initialize_data(&__text_end__, &__data_start__, &__data_end__);
  initialize_bss(&__data_end__, &__bss_end__);
  
  while( !(RCC->CR & (1<<17)) );//wait until HSE is ready
  RCC->CFGR = (1<<0);//set HSE as system clock
  while( !((RCC->CFGR & 0x0F) == 0b0101) );//wait until HSE is used as system clock
  RCC->CR &= ~(1<<0);//disable HSI clock
  
  main();
  
  NVIC_SystemReset();//if main() ever returns reset MCU
  return;
}

//default IRQ handler initiates system reset
static void default_handler()
{
  NVIC_SystemReset();
  return;
}

//EXTI 20 interrupt is only used to wake up from stop mode
static void rtc_handler()
{
  EXTI->PR = (1<<20);//clear EXTI line 20 interrupt flag
  return;
}

//EXTI line 15 interrupt is only used to wake up from stop mode
static void exti4_15()
{
  EXTI->PR = (1<<15);//clear EXTI line 15 interrupt flag
  return;
}

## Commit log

2020-10-30 new version release
    [LocalTrack-B.Cu.gbr, LocalTrack-B.Mask.gbr, LocalTrack-B.SilkS.gbr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]
2021-01-29 documentation update
    [KH-F20.FCStd]
2021-01-29 removed extra TVS diode
    [LocalTrack-B.Cu.gbr, LocalTrack-B.Mask.gbr, LocalTrack-B.SilkS.gbr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]
2023-11-14 update to newer toolchain version
    [KH-F20.FCStd, LocalTrack.kicad_pcb, LocalTrack.kicad_sch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]
